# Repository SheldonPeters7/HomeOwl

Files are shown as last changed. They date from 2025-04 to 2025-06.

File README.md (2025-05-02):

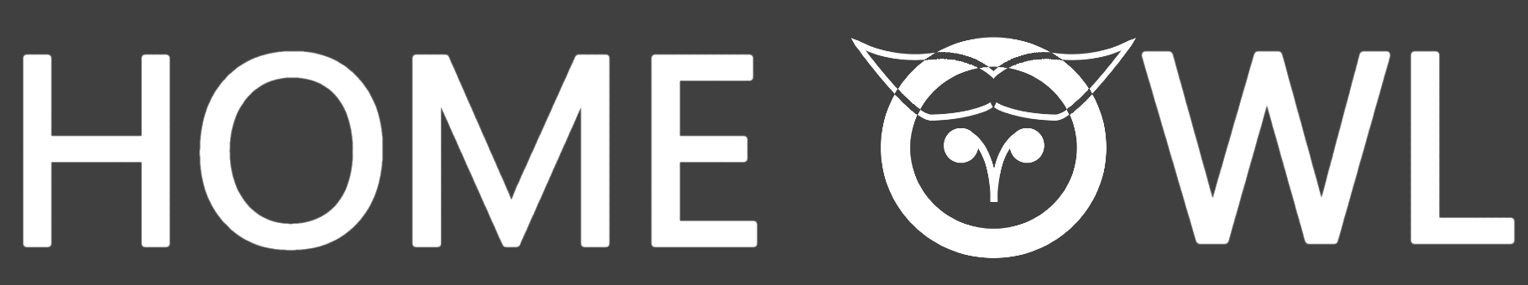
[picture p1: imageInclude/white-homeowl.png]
Home Owl

# Autonomous Security Robot

**CSU Channel Islands Capstone Project** <br>

<ins>Students:</ins> <br>
- Samantha Buckle <br>
- Dylan Dauz <br>
- Sameeh Olipani <br>
- Sheldon Peters <br>

<ins>Faculty Advisor:</ins> <br>
- Dr. Vida Vakilian

<ins>Background Information:</ins> <br>
Homes and commercial spaces face a variety of security risks like unauthorized entry or even unexpected disturbances. To address these potential issues, the Home Owl project developed a low cost, responsive platform for real time indoor surveillance in environments such as warehouses, offices, and homes. The Home Owl robot combines autonomous navigation with disturbance detection using PIR and sound sensors and offers remote control activation as well. It autonomously traverses a room, pauses briefly to allow sensor stabilization for reliable motion and audio monitoring, and sets off an alarm upon detecting anomalies. The robot’s structure was designed with 3D printed components and laser cut acrylic, resulting in a modular architecture that supports easy future upgrades.

<ins>Capstone Accomplishments Timeline</ins> <br>
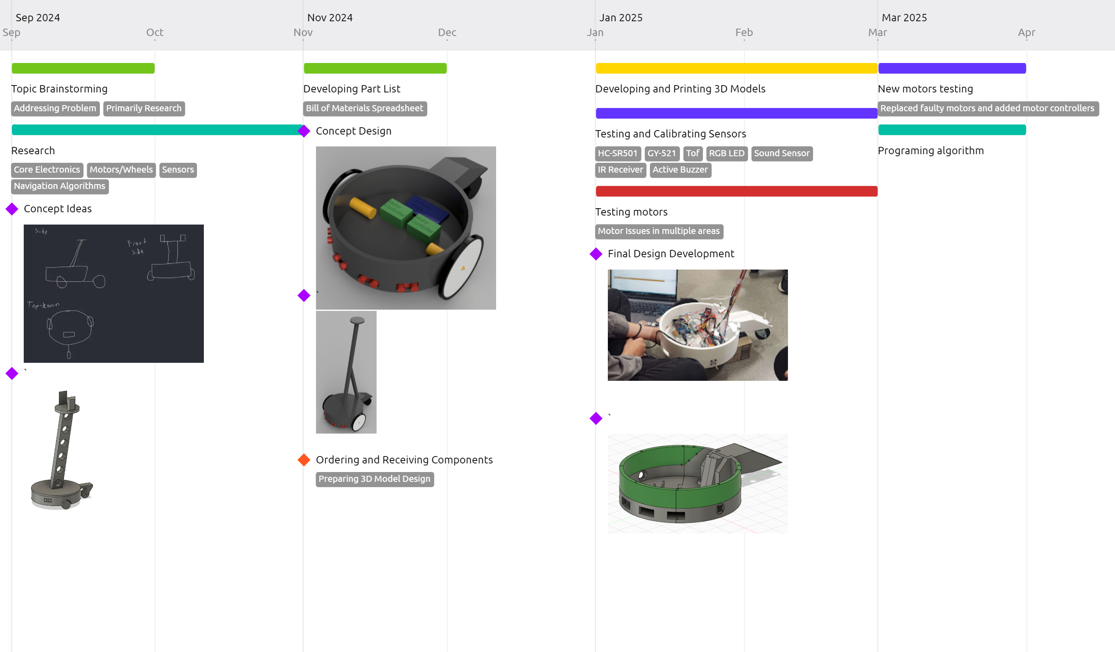
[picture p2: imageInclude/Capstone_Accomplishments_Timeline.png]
Timeline


<ins>3-D Print Model</ins> <br>
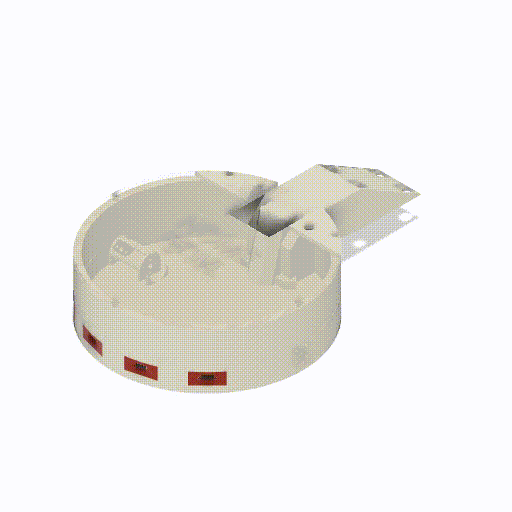
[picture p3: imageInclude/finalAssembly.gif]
Model


<ins>Video Demonstration:</ins> <br>
Home Owl (https://youtu.be/DmunYwZIAPI)

<ins>Poster Image:</ins> <br>
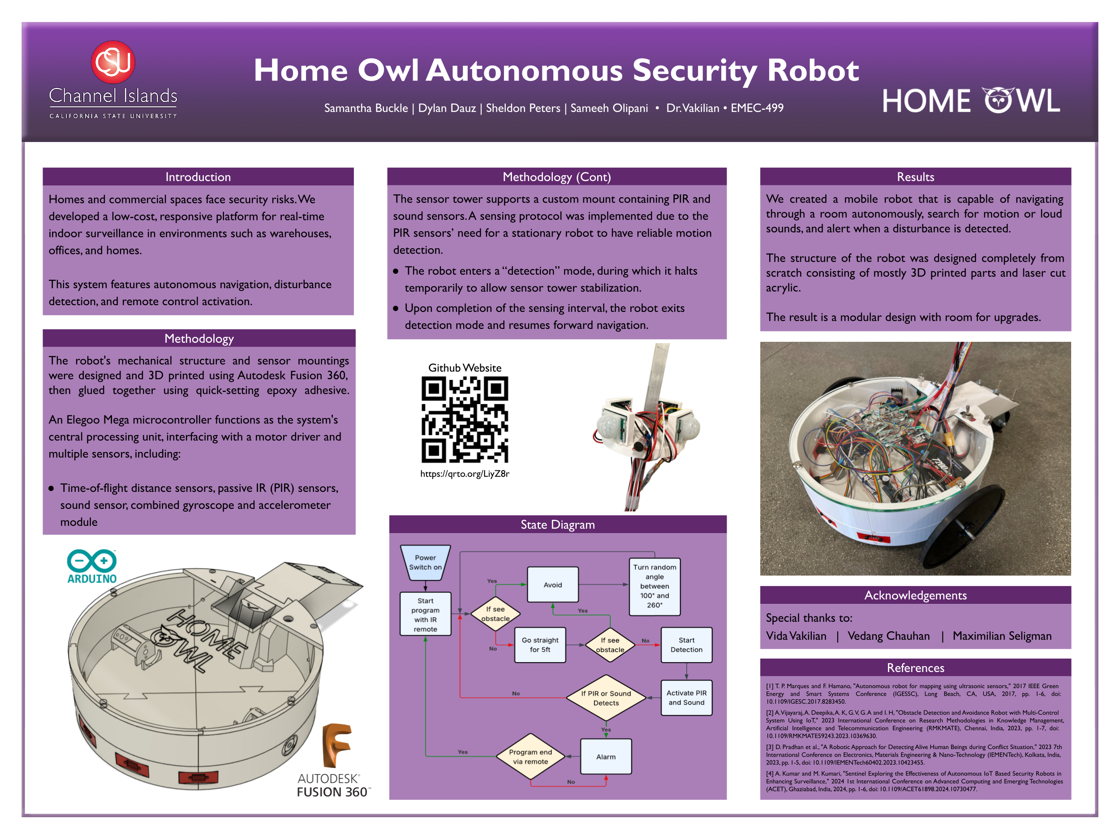
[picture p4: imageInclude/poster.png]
Poster


<ins>Wiring Diagram:</ins> <br>
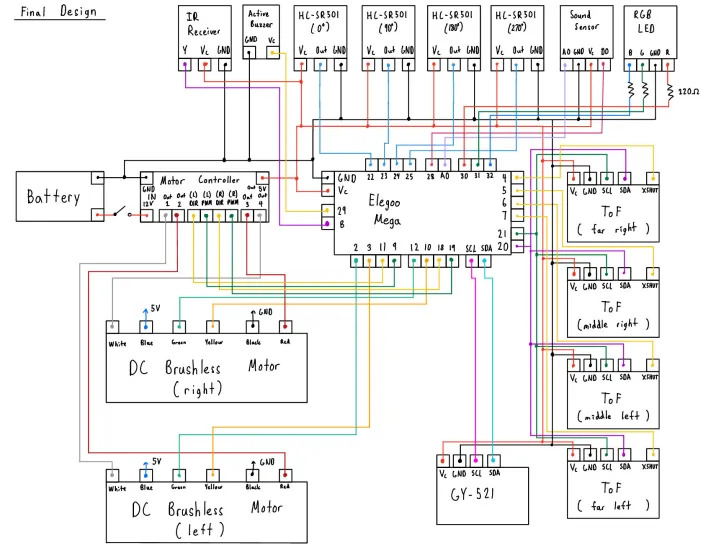
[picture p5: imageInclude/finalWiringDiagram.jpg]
Wiring


<ins>Acknowledgements:</ins> <br>
-  Dr. Vida Vakilian <br>
-  Dr. Vedang Chauhan <br>
- Maximilian Seligman <br>

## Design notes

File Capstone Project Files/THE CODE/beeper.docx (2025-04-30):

TEST CODE

int buzzerPin = 29; // Buzzer connected to digital pin 29

bool beepActive = false; // Control flag for beep mode

unsigned long previousMillis = 0;

const long beepInterval = 500; // 500ms beep toggle interval

// State variables for 3-second cycle

enum State { OFF, ON };

State currentState = OFF;

unsigned long stateStartTime = 0;

const long stateInterval = 3000; // 3 seconds per state

void setup() {

pinMode(buzzerPin, OUTPUT);

digitalWrite(buzzerPin, LOW); // Ensure buzzer starts off

stateStartTime = millis(); // Initialize state timing

}

void loop() {

unsigned long currentMillis = millis();

// Handle state transitions every 3 seconds

if (currentMillis - stateStartTime >= stateInterval) {

// Toggle state

currentState = (currentState == OFF) ? ON : OFF;

stateStartTime = currentMillis;

if (currentState == ON) {

beepActive = true; // Enable beeping

previousMillis = currentMillis; // Reset beep timer

} else {

beepActive = false; // Disable beeping

digitalWrite(buzzerPin, LOW); // Ensure buzzer is off

}

}

// Handle beep toggling when active

if (beepActive) {

if (currentMillis - previousMillis >= beepInterval) {

previousMillis = currentMillis;

digitalWrite(buzzerPin, !digitalRead(buzzerPin));

}

}

}

HEADER FILE FOR POTENTIAL IMPLEMENTATION

#ifndef Buzzer_h

#define Buzzer_h

#include <Arduino.h>

class Buzzer {

public:

Buzzer(int pin) : buzzerPin(pin), beepActive(false), previousMillis(0) {}

void init() {

pinMode(buzzerPin, OUTPUT);

digitalWrite(buzzerPin, LOW);

}

void update() {

if (beepActive) {

unsigned long currentMillis = millis();

if (currentMillis - previousMillis >= interval) {

previousMillis = currentMillis;

digitalWrite(buzzerPin, !digitalRead(buzzerPin));

}

}

}

void startBeep() {

beepActive = true;

previousMillis = millis();

digitalWrite(buzzerPin, HIGH); // Start with immediate beep

}

void stopBeep() {

beepActive = false;

digitalWrite(buzzerPin, LOW);

}

void setInterval(unsigned long newInterval) {

interval = newInterval;

}

private:

int buzzerPin;

bool beepActive;

unsigned long previousMillis;

unsigned long interval = 500; // Default 500ms interval

};

#endif

#include "Buzzer.h"

// Create buzzer instance on pin 29

Buzzer myBuzzer(29);

void setup() {

myBuzzer.init();

}

void loop() {

myBuzzer.update(); // Must call this regularly

// Example trigger - replace with your actual triggers

if (someCondition) {

myBuzzer.startBeep();

}

if (anotherCondition) {

myBuzzer.stopBeep();

}

// Rest of your code...

}

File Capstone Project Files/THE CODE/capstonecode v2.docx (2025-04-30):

const int leftencoderApin = 2;

const int leftencoderBpin = 3;

const int rightencoderApin = 18;

const int rightencoderBpin = 19;

const int leftdirpin = 11;

const int rightdirpin = 12;

const int leftpwmpin = 9;

const int rightpwmpin = 10;

int leftencoderpulse = 0; // ticks left

int rightencoderpulse = 0; // ticks right

// distance variables

double ipr = 18.85; // inches per revolution

double tpr = 950; // ticks per revolution

// PID variables

int pwm = 100; // pwm motor power

double error = 0; // set speed - actual speed

double eI = 0; // integral error

double eD = 0; // derivative error

double prev_error = 0;

const float Kp = 1.0; // proportional gain

const float Ki = 2.0; //integral gain

const float Kd = 1.0; // derivative gain

float targetAngle = 90;

int i = 0; // for motor start delay

// Odometry variables

const float wheelbase = 13.7; // inches

const float dpt = ipr / tpr;

float dL = 0; // distance left wheel traveled

float dR = 0; // distance right wheel traveled

float theta = 0;

void setup()

{

Serial.begin(9600);

pinMode(leftencoderApin, INPUT); //input_pullup to print to serial monitor..?

pinMode(leftencoderBpin, INPUT);

// Left encoder interrupts

attachInterrupt(digitalPinToInterrupt(leftencoderApin), ALeadingLeft, RISING);

attachInterrupt(digitalPinToInterrupt(leftencoderBpin), BLeadingLeft, RISING);

// Right encoder interrupts

attachInterrupt(digitalPinToInterrupt(rightencoderApin), ALeadingRight, RISING);

attachInterrupt(digitalPinToInterrupt(rightencoderBpin), BLeadingRight, RISING);

// target ticks

//targetticks = (targetdistance / ipr) * tpr;

pinMode(leftdirpin, OUTPUT);

pinMode(rightdirpin, OUTPUT);

pinMode(leftpwmpin, OUTPUT);

pinMode(rightpwmpin, OUTPUT);

analogWrite(leftpwmpin, 0);

analogWrite(rightpwmpin, 0);

delay(2000); // Allows the serial monitor to connect before robot starts

}

void loop()

{

// clockwise forward motion (hopefully)

digitalWrite(leftdirpin, HIGH);

digitalWrite(rightdirpin, LOW);

//unsigned long clock = millis();

//computePID();

//analogWrite(leftpwmpin, 255-pwm-45);

// Serial.println("before");

// Serial.println(i);

// // start delay on motors

// if(i < 1)

// {

// Serial.println("during");

// delay(2000);

// Serial.print(i);

// i++;

// }

// Serial.println("after");

// Serial.println(i);

//analogWrite(rightpwmpin, pwm);

changeAngle();

Serial.print("dl: ");

Serial.println(dL);

Serial.print("dr: ");

Serial.println(dR);

Serial.print("theta: ");

Serial.println(theta);

Serial.print("error: ");

Serial.println(error);

//Serial.print("left encoder pulse: ");

// Serial.println(leftencoderpulse);

// Serial.print(",");

// //Serial.print("right encoder pulse: ");

// Serial.println(rightencoderpulse);

delay(50);

// Serial.print("Distance Traveled: ");

// Serial.print((((leftencoderpulse + rightencoderpulse) / 2) / tpr) * ipr);

// Serial.println(" inches");

while(((leftencoderpulse + rightencoderpulse) / 2) >= tpr)

{

stopMotors();

//Serial.println("ENCODER STOPPED");

}

}

void stopMotors()

{

digitalWrite(leftdirpin, HIGH);

digitalWrite(rightdirpin, LOW);

analogWrite(leftpwmpin, 255);

analogWrite(rightpwmpin, 0);

}

void ALeadingLeft()

{

if(digitalRead(leftencoderBpin) == LOW)

{

leftencoderpulse--;

}

else

{

leftencoderpulse++;

}

}

void BLeadingLeft()

{

if(digitalRead(leftencoderApin) == LOW)

{

leftencoderpulse++;

}

else

{

leftencoderpulse--;

}

}

void ALeadingRight()

{

if(digitalRead(rightencoderBpin) == LOW)

{

rightencoderpulse++;

}

else

{

rightencoderpulse--;

}

}

void BLeadingRight()

{

if(digitalRead(rightencoderApin) == LOW)

{

rightencoderpulse--;

}

else

{

rightencoderpulse++;

}

}

void computePID()

{

error = targetAngle - theta;

eI = eI + error; // integral error

eD = prev_error - error; // derivative error

prev_error = error;

// limit overflow of intergral error

if (eI > 200)

{

eI = 0;

}

pwm = Kp * error + Ki * eI + Kd * eD; // P + I + D

if (pwm >= 360) // limit max

{

}

else if (pwm <= -360) // limit min

{

}

}

void computeAngle()

{

dL = leftencoderpulse * dpt;

dR = rightencoderpulse * dpt;

theta = (dL-dR)/wheelbase * (180/3.1415);

}

void changeAngle()

{

computeAngle();

error = targetAngle - theta;

if (error > 5) // turn left

{

digitalWrite(leftdirpin, LOW);

digitalWrite(rightdirpin, LOW);

analogWrite(leftpwmpin, 100+45);

analogWrite(rightpwmpin, 100);

} else if (error < -5) // this is the one we want to happen, turn right

{

digitalWrite(leftdirpin, HIGH);

digitalWrite(rightdirpin, HIGH);

analogWrite(leftpwmpin, 255-100-45);

analogWrite(rightpwmpin, 255-100);

}

else // default

{

stopMotors();

// digitalWrite(leftdirpin, HIGH);

// digitalWrite(rightdirpin, LOW);

// analogWrite(leftpwmpin, 255-100-45);

// analogWrite(rightpwmpin, 100);

delay(3000);

}

}

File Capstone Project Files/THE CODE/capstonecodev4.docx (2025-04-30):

#include <Wire.h>

const int leftencoderApin = 2;

const int leftencoderBpin = 3;

const int rightencoderApin = 18;

const int rightencoderBpin = 19;

const int leftdirpin = 11;

const int rightdirpin = 12;

const int leftpwmpin = 9;

const int rightpwmpin = 10;

int leftencoderpulse = 0;

int rightencoderpulse = 0;

// distance variables

double ipr = 18.85; // inches per revolution

double tpr = 900; // ticks per revolution

int targetangle = 0;

double targetdistance = 67;

int pwm = 100; // pwm motor power

// PID variables

double error = 0; // set speed - actual speed

double eI = 0; // integral error

double eD = 0; // derivative error

double prev_error = 0;

const float Kp = 1.2; // proportional gain

const float Ki = 0.3; //integral gain

const float Kd = 0; // derivative gain

float omega = 0;

float vL = 0;

float vR = 0;

int i = 0; // for motor start delay

const float wheelbase = 13.7; // inches

// Gyro Variables

const int MPU_ADDR = 0x68;

const float GYRO_SCALE = 131.0; // ±250°/s range

float yaw = 0;

float gyroZOffset = 0;

unsigned long prevTime = 0;

void setup()

{

Wire.begin();

Serial.begin(9600);

pinMode(leftencoderApin, INPUT); //input_pullup to print to serial monitor..?

pinMode(leftencoderBpin, INPUT);

// Left encoder interrupts

attachInterrupt(digitalPinToInterrupt(leftencoderApin), ALeadingLeft, RISING);

attachInterrupt(digitalPinToInterrupt(leftencoderBpin), BLeadingLeft, RISING);

// Right encoder interrupts

attachInterrupt(digitalPinToInterrupt(rightencoderApin), ALeadingRight, RISING);

attachInterrupt(digitalPinToInterrupt(rightencoderBpin), BLeadingRight, RISING);

pinMode(leftdirpin, OUTPUT);

pinMode(rightdirpin, OUTPUT);

pinMode(leftpwmpin, OUTPUT);

pinMode(rightpwmpin, OUTPUT);

analogWrite(leftpwmpin, 0);

analogWrite(rightpwmpin, 0);

// Gyro setup

Wire.beginTransmission(MPU_ADDR);

Wire.write(0x6B); // PWR_MGMT_1

Wire.write(0); // Wake up

Wire.endTransmission();

calibrateGyro();

prevTime = micros();

delay(2000); // Allows the serial monitor to connect before robot starts

}

void loop()

{

// clockwise forward motion

// digitalWrite(leftdirpin, HIGH);

// digitalWrite(rightdirpin, LOW);

//unsigned long clock = millis();

//computePID();

//analogWrite(leftpwmpin, 255-pwm-45);

// // start delay on motors

// if(i < 1)

// {

// delay(2000);

// i++;

// }

//analogWrite(rightpwmpin, pwm);

if(i < 1)

{

targetangle = yaw + 90;

i++;

}

computePID();

rotateRobotRight();

//Serial.print("left encoder pulse: ");

// Serial.println(leftencoderpulse);

// //Serial.print("right encoder pulse: ");

// Serial.println(rightencoderpulse);

// Read gyro Z-axis

int16_t rawGyroZ = readGyroZ();

float gyroZ = (rawGyroZ - gyroZOffset) / GYRO_SCALE;

// Calculate delta time

unsigned long currentTime = micros();

float dt = (currentTime - prevTime) / 1000000.0;

prevTime = currentTime;

// Integrate angular velocity to get yaw

yaw -= gyroZ * dt;

Serial.print("Yaw: ");

Serial.println(yaw, 2);

}

void stopMotors()

{

digitalWrite(leftdirpin, HIGH);

digitalWrite(rightdirpin, LOW);

analogWrite(leftpwmpin, 255);

analogWrite(rightpwmpin, 0);

}

void ALeadingLeft()

{

if(digitalRead(leftencoderBpin) == LOW)

{

leftencoderpulse--;

}

else

{

leftencoderpulse++;

}

}

void BLeadingLeft()

{

if(digitalRead(leftencoderApin) == LOW)

{

leftencoderpulse++;

}

else

{

leftencoderpulse--;

}

}

void ALeadingRight()

{

if(digitalRead(rightencoderBpin) == LOW)

{

rightencoderpulse++;

}

else

{

rightencoderpulse--;

}

}

void BLeadingRight()

{

if(digitalRead(rightencoderApin) == LOW)

{

rightencoderpulse--;

}

else

{

rightencoderpulse++;

}

}

void computePID()

{

error = targetangle - yaw;

eI = eI + error; // integral error

eD = prev_error - error; // derivative error

prev_error = error;

// limit overflow of intergral error

if (eI > 200)

{

eI = 0;

}

omega = Kp * error + Ki * eI + Kd * eD; // calculating rate of change of angle (rad/s)

if (omega >= 100) // limit max

{

omega = 100;

}

else if (omega <= 0) // limit min

{

omega = 0;

}

}

void rotateRobotRight()

{

vL = ((omega * wheelbase) / 2);

vR = ((omega * wheelbase) / 2);

if(targetangle > yaw)

{

digitalWrite(leftdirpin, HIGH);

digitalWrite(rightdirpin, HIGH);

analogWrite(leftpwmpin, 255-(vL*0.152) - 45);

analogWrite(rightpwmpin, 255-(vR*0.152));

} else

{

stopMotors();

}

}

int16_t readGyroZ()

{

Wire.beginTransmission(MPU_ADDR);

Wire.write(0x47); // GYRO_ZOUT_H

Wire.endTransmission(false);

Wire.requestFrom(MPU_ADDR, 2, true);

return Wire.read() << 8 | Wire.read();

}

void calibrateGyro()

{

Serial.println("Calibrating gyro... Keep sensor stationary!");

delay(1000);

long total = 0;

for(int i = 0; i < 1000; i++) {

total += readGyroZ();

delay(1);

}

gyroZOffset = total / 1000.0;

Serial.print("Calibration offset: ");

Serial.println(gyroZOffset);

}

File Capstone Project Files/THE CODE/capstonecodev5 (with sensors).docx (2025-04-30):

TRY (due to timer conflicts with pins)

// Motor Control (swap PWM pins)

const int leftpwmpin = 11; // Originally 9 (Timer1)

const int rightpwmpin = 12; // Originally 10 (Timer1)

const int leftdirpin = 9; // Swap direction pins

const int rightdirpin = 10;

---_------------------

// Arduino Mega

#elif defined(__AVR_ATmega1280__) || defined(__AVR_ATmega2560__)

//#define IR_USE_TIMER1

//#define IR_USE_TIMER2

//#define IR_USE_TIMER3

#define IR_USE_TIMER5 // Use Timer5 for IR decoding

// Add this after the Mega section

#elif defined(IR_USE_TIMER5)

#define TIMER_RESET_INTR_PENDING

#define TIMER_CONFIG_KHZ(val) ((val) / (timer5_prescale * 0.001))

#define TIMER_ENABLE_INTR (TIMSK5 = _BV(OCIE5A))

#define TIMER_DISABLE_INTR (TIMSK5 = 0)

#define TIMER_INTR_NAME TIMER5_COMPA_vect

#define TIMER_COUNT_TOP (F_CPU / timer5_prescale / 1000)

#if defined(TCCR5A) && defined(TCCR5B)

#define TIMER_CONFIG_GPIO() (DDRL |= _BV(PL0))

#define TIMER_PWM_PIN PL0 // Arduino Mega pin 44

#endif

#endif // End of timer selection block

—----

________________________________________________________--

#include <IRremote.h>

// IR Configuration

const int receiver = 8; // IR receiver pin

IRrecv irrecv(receiver); // Create IR receiver object

static uint32_t last_decodedRawData = 0; // Stores last received code

// State management

enum SystemState {

OFF,

STANDBY,

MOVING,

SEARCHING

};

SystemState currentState = OFF;

void setup() {

// IR initialization

irrecv.enableIRIn(); // Start the IR receiver

}

void loop() {

// Check for IR input

if (irrecv.decode()) {

translateIR();

irrecv.resume();

}

}

void translateIR() {

if (irrecv.decode()) {

static unsigned long lastIRTime = 0;

unsigned long currentTime = millis();

// Debounce - ignore repeats within 200ms

if (currentTime - lastIRTime > 200) {

lastIRTime = currentTime;

switch(irrecv.decodedIRData.decodedRawData) {

case 0xBA45FF00: // POWER button

if (currentState == OFF) {

currentState = STANDBY;

} else if (currentState == STANDBY) {

currentState = MOVING;

} else {

currentState = OFF;

}

break;

case 0xB847FF00: // RESET button

currentState = STANDBY;

break;

}

}

}

}

#include <Wire.h>

#include <Adafruit_VL53L0X.h>

const int leftencoderApin = 2;

const int leftencoderBpin = 3;

const int rightencoderApin = 18;

const int rightencoderBpin = 19;

const int leftdirpin = 11;

const int rightdirpin = 12;

const int leftpwmpin = 9;

const int rightpwmpin = 10;

int leftencoderpulse = 0;

int rightencoderpulse = 0;

int currentleftencoderpulse = 0;

int currentrightencoderpulse = 0;

// distance variables

double ipr = 18.85; // inches per revolution

double tpr = 900; // ticks per revolution

int targetangle = 0;

int pwm = 100; // pwm motor power

// PID variables

double error = 0; // set speed - actual speed

double eI = 0; // integral error

double eD = 0; // derivative error

double prev_error = 0;

const float Kp = 1.2; // proportional gain

const float Ki = 0.3; //integral gain

const float Kd = 0; // derivative gain

float omega = 0;

float vL = 0;

float vR = 0;

int i = 0; // for motor start delay

const float wheelbase = 13.7; // inches

bool runonceturn = false; // the run once bool for turning

// Gyro Variables

const int MPU_ADDR = 0x68;

const float GYRO_SCALE = 131.0; // ±250°/s range

float yaw = 0;

float gyroZOffset = 0;

unsigned long prevTime = 0;

// const unsigned long yawPrintInterval = 1000; // Print every 1000 ms

// unsigned long lastYawPrint = 0; // Timing tracker

// ToF Variables

Adafruit_VL53L0X loxFarRight = Adafruit_VL53L0X(); // Pin 4

Adafruit_VL53L0X loxMidRight = Adafruit_VL53L0X(); // Pin 5

Adafruit_VL53L0X loxMidLeft = Adafruit_VL53L0X(); // Pin 6

Adafruit_VL53L0X loxFarLeft = Adafruit_VL53L0X(); // Pin 7

#define XSHUT_FAR_RIGHT 4

#define XSHUT_MID_RIGHT 5

#define XSHUT_MID_LEFT 6

#define XSHUT_FAR_LEFT 7

unsigned long lastToFRead = 0;

float distanceFarRight = 0;

float distanceMidRight = 0;

float distanceMidLeft = 0;

float distanceFarLeft = 0;

float distancethreshold = 200;

bool farRight = (distanceFarRight <= distancethreshold);

bool midRight = (distanceMidRight <= distancethreshold);

bool midLeft = (distanceMidLeft <= distancethreshold);

bool farLeft = (distanceFarLeft <= distancethreshold);

/***************************** Sound & Motion Sensors *****************************/

// Sound and Motion Variables

const int sensorAnalogPin = A0; // Analog input

const int sensorDigitalPin = 28; // Digital input D28

const int ledPin = LED_BUILTIN; // Built-in LED

// Sound detection settings

unsigned long lastNoiseTime = 0;

const unsigned long noiseCooldown = 1000;

int loudNoiseThreshold;

int quietLevel;

// PIR Sensor Pins (Inputs)

int pirPin1 = 22; // HC-SR501 #1

int pirPin2 = 23; // HC-SR501 #2

int pirPin3 = 24; // HC-SR501 #3

int pirPin4 = 25; // HC-SR501 #4

// Motion detection settings

unsigned long lastMotionTime = 0;

const unsigned long motionCooldown = 1000;

/***************************** Start of Setup *****************************/

void setup()

{

Serial.begin(115200);

Wire.begin();

pinMode(leftencoderApin, INPUT); //input_pullup to print to serial monitor..?

pinMode(leftencoderBpin, INPUT);

// Left encoder interrupts

attachInterrupt(digitalPinToInterrupt(leftencoderApin), ALeadingLeft, RISING);

attachInterrupt(digitalPinToInterrupt(leftencoderBpin), BLeadingLeft, RISING);

// Right encoder interrupts

attachInterrupt(digitalPinToInterrupt(rightencoderApin), ALeadingRight, RISING);

attachInterrupt(digitalPinToInterrupt(rightencoderBpin), BLeadingRight, RISING);

pinMode(leftdirpin, OUTPUT);

pinMode(rightdirpin, OUTPUT);

pinMode(leftpwmpin, OUTPUT);

pinMode(rightpwmpin, OUTPUT);

// digitalWrite(leftdirpin, HIGH);

// digitalWrite(rightdirpin, LOW);

analogWrite(leftpwmpin, 0);

analogWrite(rightpwmpin, 0);

// Gyro setup (Initialize MPU)

Wire.beginTransmission(MPU_ADDR);

Wire.write(0x6B); // PWR_MGMT_1

Wire.write(0); // Wake up

Wire.endTransmission();

calibrateGyro();

prevTime = micros();

// Initialize ToF sensors

pinMode(XSHUT_FAR_RIGHT, OUTPUT);

pinMode(XSHUT_MID_RIGHT, OUTPUT);

pinMode(XSHUT_MID_LEFT, OUTPUT);

pinMode(XSHUT_FAR_LEFT, OUTPUT);

initializeSensor(loxFarRight, XSHUT_FAR_RIGHT, 0x30, "Far Right");

initializeSensor(loxMidRight, XSHUT_MID_RIGHT, 0x31, "Middle Right");

initializeSensor(loxMidLeft, XSHUT_MID_LEFT, 0x32, "Middle Left");

initializeSensor(loxFarLeft, XSHUT_FAR_LEFT, 0x33, "Far Left");

// Initialize sound/motion sensors

pinMode(sensorDigitalPin, INPUT);

pinMode(ledPin, OUTPUT);

pinMode(pirPin1, INPUT);

pinMode(pirPin2, INPUT);

pinMode(pirPin3, INPUT);

pinMode(pirPin4, INPUT);

calibrateSensor();

Serial.println("System initialization complete!");

delay(2000); // Allows the serial monitor to connect before robot starts

}

void loop()

{

// clockwise forward motion

//digitalWrite(leftdirpin, HIGH);

//digitalWrite(rightdirpin, LOW);

//unsigned long clock = millis();

//computePID();

//analogWrite(leftpwmpin, 255-pwm-45);

// start delay on motors

// if(i < 1)

// {

// delay(2000);

// i++;

// }

//analogWrite(rightpwmpin, pwm);

readAllToFSensors();

//delay(3000);

if(checkFrontObstacle())

{

double randomTurn = random(100, 260);

Serial.println("Object Detected");

readAllToFSensors();

runonceturn = true;

stopMotors();

targetangle = yaw + randomTurn;

// Serial.println(farRight);

// Serial.println(farLeft);

// Serial.println(midRight);

// Serial.println(midLeft);

delay(1000);

while(runonceturn == true)

{

updateGyro();

Serial.println(yaw);

Serial.println(targetangle);

Serial.println("TURNING");

computePID();

turnRight();

//Serial.println("I Turned");

//runonceturn = false;

Serial.println(runonceturn);

}

Serial.println("I finished turning");

} else if ((leftencoderpulse < (currentleftencoderpulse + 60*(tpr/ipr))) && (rightencoderpulse < (currentrightencoderpulse + 60*(tpr/ipr))))// left encoder pulse and right in coder pulse less than current left encoder pulse plus 5ft and current right encoder pulse pluse 5ft

{

Serial.println("normal case ");

digitalWrite(leftdirpin, HIGH);

digitalWrite(rightdirpin, LOW);

analogWrite(leftpwmpin, 255-pwm-45);

analogWrite(rightpwmpin, pwm);

updateGyro();

} else

{

stopMotors();

delay(3000);

//intruderSense()

currentleftencoderpulse = leftencoderpulse;

currentrightencoderpulse = rightencoderpulse;

}

// Handle ToF sensor readings

if (millis() - lastToFRead >= 1000) {

readAllToFSensors();

lastToFRead = millis();

}

// Monitor environment

//checkSound();

//checkMotion();

}

void stopMotors()

{

digitalWrite(leftdirpin, HIGH);

digitalWrite(rightdirpin, LOW);

analogWrite(leftpwmpin, 255);

analogWrite(rightpwmpin, 0);

}

void ALeadingLeft()

{

if(digitalRead(leftencoderBpin) == LOW)

{

leftencoderpulse--;

}

else

{

leftencoderpulse++;

}

}

void BLeadingLeft()

{

if(digitalRead(leftencoderApin) == LOW)

{

leftencoderpulse++;

}

else

{

leftencoderpulse--;

}

}

void ALeadingRight()

{

if(digitalRead(rightencoderBpin) == LOW)

{

rightencoderpulse++;

}

else

{

rightencoderpulse--;

}

}

void BLeadingRight()

{

if(digitalRead(rightencoderApin) == LOW)

{

rightencoderpulse--;

}

else

{

rightencoderpulse++;

}

}

void computePID()

{

error = targetangle - yaw;

eI = eI + error; // integral error

eD = prev_error - error; // derivative error

prev_error = error;

// limit overflow of intergral error

if (eI > 200)

{

eI = 0;

}

omega = Kp * error + Ki * eI + Kd * eD; // calculating rate of change of angle (rad/s)

if (omega >= 150) // limit max

{

omega = 150;

}

else if (omega <= 0) // limit min

{

omega = 0;

}

}

void turnRight()

{

vL = ((omega * wheelbase) / 2);

vR = ((omega * wheelbase) / 2);

if(targetangle > yaw)

{

digitalWrite(leftdirpin, HIGH);

digitalWrite(rightdirpin, HIGH);

analogWrite(leftpwmpin, 255-(vL*0.152) - 45);

analogWrite(rightpwmpin, 255-(vR*0.152));

} else

{

stopMotors();

runonceturn = false;

}

}

int16_t readGyroZ()

{

Wire.beginTransmission(MPU_ADDR);

Wire.write(0x47); // GYRO_ZOUT_H

Wire.endTransmission(false);

Wire.requestFrom(MPU_ADDR, 2, true);

return Wire.read() << 8 | Wire.read();

}

void calibrateGyro()

{

Serial.println("Calibrating gyro... Keep sensor stationary!");

delay(1000);

long total = 0;

for(int i = 0; i < 1000; i++)

{

total += readGyroZ();

delay(1);

}

gyroZOffset = total / 1000.0;

Serial.print("Calibration offset: ");

Serial.println(gyroZOffset);

}

void updateGyro()

{

int16_t rawGyroZ = readGyroZ();

float gyroZ = (rawGyroZ - gyroZOffset) / GYRO_SCALE;

unsigned long currentTime = micros();

float dt = (currentTime - prevTime) / 1000000.0;

prevTime = currentTime;

yaw -= gyroZ * dt;

}

/********************************* ToF Functions *********************************/

void initializeSensor(Adafruit_VL53L0X &sensor, int xshutPin, uint8_t newAddress, const char* position)

{

digitalWrite(xshutPin, LOW);

delay(10);

digitalWrite(xshutPin, HIGH);

delay(10);

if (!sensor.begin(newAddress))

{

Serial.print(position);

Serial.println(" sensor failed to boot!");

while(1);

}

Serial.print(position);

Serial.print(" sensor initialized at 0x");

Serial.println(newAddress, HEX);

}

int readSensor(Adafruit_VL53L0X &sensor, const char* position)

{

VL53L0X_RangingMeasurementData_t measure;

sensor.rangingTest(&measure, false);

if(measure.RangeStatus != 4)

{

Serial.print(position);

Serial.print(": ");

Serial.print(measure.RangeMilliMeter);

Serial.println(" mm");

return(measure.RangeMilliMeter);

} else

{

Serial.print(position);

Serial.println(": Out of range");

return(-1);

}

}

void readAllToFSensors()

{

distanceFarRight = readSensor(loxFarRight, "Far Right");

distanceMidRight = readSensor(loxMidRight, "Middle Right");

distanceMidLeft = readSensor(loxMidLeft, "Middle Left");

distanceFarLeft = readSensor(loxFarLeft, "Far Left");

}

bool checkFrontObstacle()

{

VL53L0X_RangingMeasurementData_t measure;

bool obstacleDetected = false;

// Check first sensor

loxFarLeft.rangingTest(&measure, false);

obstacleDetected |= (measure.RangeMilliMeter <= 400 && measure.RangeStatus != 4);

// Check second sensor

loxMidLeft.rangingTest(&measure, false);

obstacleDetected |= (measure.RangeMilliMeter <= 400 && measure.RangeStatus != 4);

// Check third sensor

loxMidRight.rangingTest(&measure, false);

obstacleDetected |= (measure.RangeMilliMeter <= 400 && measure.RangeStatus != 4);

// Check fourth sensor

loxFarRight.rangingTest(&measure, false);

obstacleDetected |= (measure.RangeMilliMeter <= 400 && measure.RangeStatus != 4);

return obstacleDetected;

}

/****************************** Sound/Motion Functions ****************************/

void calibrateSensor()

{

long sum = 0;

for(int i = 0; i < 50; i++) sum += analogRead(sensorAnalogPin);

quietLevel = sum / 50;

loudNoiseThreshold = 400; // Hard-coded for testing

Serial.println("Sound sensor calibrated");

}

void checkSound()

{

int analogValue = analogRead(sensorAnalogPin);

int digitalValue = digitalRead(sensorDigitalPin);

if((analogValue > loudNoiseThreshold) && (digitalValue == HIGH) &&

(millis() - lastNoiseTime > noiseCooldown)) {

handleNoiseDetection(analogValue);

triggerActionSound();

}

}

void handleNoiseDetection(int noiseLevel)

{

lastNoiseTime = millis();

Serial.print("LOUD NOISE! Level: ");

Serial.println(noiseLevel);

for(int i = 0; i < 3; i++)

{

digitalWrite(ledPin, HIGH);

delay(100);

digitalWrite(ledPin, LOW);

delay(100);

}

}

void triggerActionSound()

{

Serial.println("Action: Sound detected!");

}

void checkMotion()

{

if((digitalRead(pirPin1) || digitalRead(pirPin2) ||

digitalRead(pirPin3) || digitalRead(pirPin4)) &&

(millis() - lastMotionTime > motionCooldown))

{

handleMotionDetection();

}

}

void handleMotionDetection()

{

lastMotionTime = millis();

Serial.println("Motion detected");

}

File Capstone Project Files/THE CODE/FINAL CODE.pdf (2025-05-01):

#include <Wire.h>

#include <Adafruit_VL53L0X.h> #include <IRremote.h>

const int leftencoderApin = 2; const int leftencoderBpin = 3; const int rightencoderApin = 18; const int rightencoderBpin = 19; const int leftdirpin = 9;
const int rightdirpin = 10; const int leftpwmpin = 11; const int rightpwmpin = 12;

int leftencoderpulse = 0;
int rightencoderpulse = 0;
int currentleftencoderpulse = 0; int currentrightencoderpulse = 0;
// distance variables
double ipr = 18.85; // inches per revolution double tpr = 900; // ticks per revolution int targetangle = 0;
int pwm = 100; // pwm motor power
int offset = 5; // motor power offset
// PID variables
double error = 0; // set speed - actual speed double eI = 0; // integral error
double eD = 0; // derivative error
double prev_error = 0;
const float Kp = 1.8; // proportional gain const float Ki = 0.4; //integral gain const float Kd = 0.05; // derivative gain float omega = 0;
float vL = 0;
float vR = 0;
int i = 0; // for motor start delay
const float wheelbase = 13.7; // inches
bool runonceturn = false; // the run once bool for turning // Gyro Variables
const int MPU_ADDR = 0x68;

const float GYRO_SCALE = 131.0; // ±250°/s range float yaw = 0;
float gyroZOffset = 0;
unsigned long prevTime = 0;
// IR Configuration
const int receiver = 8; | // IR receiver pin
IRrecv irrecv(receiver); | // Create IR receiver object
static uint32_t last_decodedRawData = 0; // Stores last received code // State management
enum SystemState {
OFF,
STANDBY,
MOVING,
SEARCHING
};
SystemState currentState = OFF;
// ToF Variables
Adafruit_VL53L0X loxFarRight = Adafruit_VL53L0X(); // Pin 4 Adafruit_VL53L0X loxMidRight = Adafruit_VL53L0X(); // Pin 5
Adafruit_VL53L0X loxMidLeft = Adafruit_VL53L0X(); | // Pin 6
Adafruit_VL53L0X loxFarLeft = Adafruit_VL53L0X(); | // Pin 7

#define XSHUT_FAR_RIGHT 4

#define XSHUT_MID_RIGHT 5

#define XSHUT_MID_LEFT 6

#define XSHUT_FAR_LEFT 7

unsigned long lastToFRead = 0;

float distanceFarRight = 0; float distanceMidRight = 0; float distanceMidLeft = 0; float distanceFarLeft = 0;
float distancethreshold = 200;
bool farRight = (distanceFarRight <= distancethreshold); bool midRight = (distanceMidRight <= distancethreshold); bool midLeft = (distanceMidLeft <= distancethreshold); bool farLeft = (distanceFarLeft <= distancethreshold);

// Sound and Motion Variables

const int sensorAnalogPin = A0; | // Analog input
const int sensorDigitalPin = 28; | // Digital input D28
const int ledPin = LED_BUILTIN; | // Built-in LED
const int buzzerPin = 29; | // Buzzer output
unsigned long lastDisturbanceTime = 0;
const unsigned long debounceTime = 500; // 0.5s debounce

// LED Configuration
#define RED 30

#define GREEN 31

#define BLUE 32

// Search mode variables
bool disturbanceDetected = false;
int flashState = 0;
const long beepInterval = 500; // 500ms beep/flash interval

// Sound detection settings
unsigned long lastNoiseTime = 0;
const unsigned long noiseCooldown = 1000; int loudNoiseThreshold;
int quietLevel;

unsigned long startMillis;
unsigned long currentMillis;
unsigned long detectionDuration = 10000; // 10 seconds in milliseconds

// PIR Sensor Pins (Inputs)
int pirPin1 = 22; // HC-SR501 #1 int pirPin2 = 23; // HC-SR501 #2 int pirPin3 = 24; // HC-SR501 #3 int pirPin4 = 25; // HC-SR501 #4

// Motion detection settings
unsigned long lastMotionTime = 0;
const unsigned long motionCooldown = 1000;

/***************************** Start of Setup *****************************/

void setup()
{

Serial.begin(115200);
Wire.begin();
pinMode(leftencoderApin, INPUT); pinMode(leftencoderBpin, INPUT);
// Left encoder interrupts attachInterrupt(digitalPinToInterrupt(leftencoderApin), ALeadingLeft, RISING); attachInterrupt(digitalPinToInterrupt(leftencoderBpin), BLeadingLeft, RISING); // Right encoder interrupts attachInterrupt(digitalPinToInterrupt(rightencoderApin), ALeadingRight, RISING);
attachInterrupt(digitalPinToInterrupt(rightencoderBpin), BLeadingRight, RISING);
pinMode(leftdirpin, OUTPUT);
pinMode(rightdirpin, OUTPUT); pinMode(leftpwmpin, OUTPUT); pinMode(rightpwmpin, OUTPUT); analogWrite(leftpwmpin, 0); analogWrite(rightpwmpin, 0);

pinMode(RED, OUTPUT);
pinMode(GREEN, OUTPUT);
pinMode(BLUE, OUTPUT);
digitalWrite(RED, HIGH);
digitalWrite(GREEN, LOW);
digitalWrite(BLUE, LOW);
// Gyro setup (Initialize MPU) Wire.beginTransmission(MPU_ADDR); Wire.write(0x6B); // PWR_MGMT_1 Wire.write(0); // Wake up
Wire.endTransmission();
calibrateGyro();
prevTime = micros();
// Initialize ToF sensors
pinMode(XSHUT_FAR_RIGHT, OUTPUT); pinMode(XSHUT_MID_RIGHT, OUTPUT); pinMode(XSHUT_MID_LEFT, OUTPUT);

pinMode(XSHUT_FAR_LEFT, OUTPUT);

initializeSensor(loxFarRight, XSHUT_FAR_RIGHT, 0x30, "Far Right"); initializeSensor(loxMidRight, XSHUT_MID_RIGHT, 0x31, "Middle Right"); initializeSensor(loxMidLeft, XSHUT_MID_LEFT, 0x32, "Middle Left"); initializeSensor(loxFarLeft, XSHUT_FAR_LEFT, 0x33, "Far Left");
// Initialize sound/motion sensors
pinMode(sensorDigitalPin, INPUT);
pinMode(ledPin, OUTPUT);
pinMode(pirPin1, INPUT);
pinMode(pirPin2, INPUT);
pinMode(pirPin3, INPUT);
pinMode(pirPin4, INPUT);
pinMode(buzzerPin, OUTPUT);
// IR initialization
irrecv.enableIRIn(); // Start the IR receiver calibrateSensor();
Serial.println("System initialization complete!");
delay(200); // Allows the serial monitor to connect before robot starts }

void loop()
{
// Check for IR input
if (irrecv.decode())
{
translateIR();
irrecv.resume();
}
readAllToFSensors(); // constantly checks values of ToF sensors to see if something is within range
if(currentState == OFF) {
stopMotors();
digitalWrite(RED, HIGH);
digitalWrite(GREEN, LOW);
digitalWrite(BLUE, LOW);
digitalWrite(buzzerPin, LOW); }

if(currentState == MOVING) { digitalWrite(buzzerPin, LOW); if(checkFrontObstacle()) // OBSTACLE CASE {
digitalWrite(buzzerPin, LOW);
double randomTurn = random(100, 260); // generate random angle to turn to Serial.println("Object Detected");
readAllToFSensors();
runonceturn = true; // prepare to turn stopMotors();
targetangle = yaw + randomTurn;

delay(1000);
// starts turning and updating gyro/pid as it turns while(runonceturn == true)
{
updateGyro();
computePID();
turnRight();
}
} else if ((leftencoderpulse < (currentleftencoderpulse + 84*(tpr/ipr))) && (rightencoderpulse < (currentrightencoderpulse + 84*(tpr/ipr))))// left encoder pulse and right in coder pulse less than current left encoder pulse plus 5ft and current right encoder pulse pluse 5ft
{
// NORMAL CASE | Green (G = HIGH)
digitalWrite(RED, LOW);
digitalWrite(GREEN, HIGH); digitalWrite(BLUE, LOW);
digitalWrite(buzzerPin, LOW); digitalWrite(leftdirpin, HIGH); digitalWrite(rightdirpin, LOW); analogWrite(leftpwmpin, 255-pwm-offset); // OFFSET LINE analogWrite(rightpwmpin, pwm);
updateGyro();
} else
{
// SENSING CASE
stopMotors();

// Blue (B=HIGH) Stablizing digitalWrite(RED, LOW);
digitalWrite(GREEN, LOW);
digitalWrite(BLUE, HIGH);
delay(2500); // allows for sensor tower to stop wobbling
// sense
startMillis = millis(); // Record the start time when entering the else loop

while (millis() - startMillis < detectionDuration) {
// Searching
digitalWrite(RED, LOW);
digitalWrite(GREEN, HIGH); digitalWrite(BLUE, HIGH);
if (checkDisturbances())
{
disturbanceDetected = true; flashSearchLights();
}
// Optional: Add a small delay to prevent overwhelming the loop delay(100);
}
currentleftencoderpulse = leftencoderpulse; currentrightencoderpulse = rightencoderpulse; }
}
// Handle ToF sensor readings
if (millis() - lastToFRead >= 1000) {
readAllToFSensors();
lastToFRead = millis();
}
}

void stopMotors()
{
digitalWrite(leftdirpin, HIGH); digitalWrite(rightdirpin, LOW);

analogWrite(leftpwmpin, 255); analogWrite(rightpwmpin, 0); }

void ALeadingLeft()
{
if(digitalRead(leftencoderBpin) == LOW) {
leftencoderpulse--;
}
else
{
leftencoderpulse++;
}
}

void BLeadingLeft()
{
if(digitalRead(leftencoderApin) == LOW) {
leftencoderpulse++;
}
else
{
leftencoderpulse--;
}
}

void ALeadingRight()
{
if(digitalRead(rightencoderBpin) == LOW) {
rightencoderpulse++;
}
else
{
rightencoderpulse--;
}
}

void BLeadingRight()
{
if(digitalRead(rightencoderApin) == LOW) {
rightencoderpulse--;
}
else
{
rightencoderpulse++;
}
}
void computePID()
{
error = targetangle - yaw;
eI = eI + error; // integral error
eD = prev_error - error; // derivative error prev_error = error;

// limit overflow of intergral error if (eI > 200)
{
eI = 0;
}
omega = Kp * error + Ki * eI + Kd * eD; // calculating rate of change of angle (rad/s)

if (omega >= 100) // limit max {
omega = 100;
}
else if (omega <= 0) // limit min {
omega = 0;
}
}
void turnRight()
{
vL = ((omega * wheelbase) / 2); vR = ((omega * wheelbase) / 2);

if(targetangle > yaw)
{
digitalWrite(leftdirpin, HIGH);
digitalWrite(rightdirpin, HIGH);
analogWrite(leftpwmpin, 255-(vL*0.152)-45); // OFFSET LINE analogWrite(rightpwmpin, 255-(vR*0.152));
} else
{
stopMotors();
runonceturn = false;
}
}

int16_t readGyroZ()
{
Wire.beginTransmission(MPU_ADDR); Wire.write(0x47); // GYRO_ZOUT_H Wire.endTransmission(false); Wire.requestFrom(MPU_ADDR, 2, true);
return Wire.read() << 8 | Wire.read();
}

void calibrateGyro()
{
Serial.println("Calibrating gyro... Keep sensor stationary!"); delay(1000);

long total = 0;
for(int i = 0; i < 1000; i++) {
total += readGyroZ();
delay(1);
}
gyroZOffset = total / 1000.0; Serial.print("Calibration offset: "); Serial.println(gyroZOffset);
}

void updateGyro()

{
int16_t rawGyroZ = readGyroZ();
float gyroZ = (rawGyroZ - gyroZOffset) / GYRO_SCALE;

unsigned long currentTime = micros();
float dt = (currentTime - prevTime) / 1000000.0; prevTime = currentTime;

yaw -= gyroZ * dt;
}

/********************************* ToF Functions *********************************/
void initializeSensor(Adafruit_VL53L0X &sensor, int xshutPin, uint8_t newAddress, const char* position)
{
digitalWrite(xshutPin, LOW); delay(10);
digitalWrite(xshutPin, HIGH); delay(10);
if (!sensor.begin(newAddress)) {
Serial.print(position);
Serial.println(" sensor failed to boot!"); while(1);
}
Serial.print(position);
Serial.print(" sensor initialized at 0x"); Serial.println(newAddress, HEX);
}

int readSensor(Adafruit_VL53L0X &sensor, const char* position) {
VL53L0X_RangingMeasurementData_t measure; sensor.rangingTest(&measure, false);

if(measure.RangeStatus != 4)
{

Serial.print(position);
Serial.print(": ");
Serial.print(measure.RangeMilliMeter); Serial.println(" mm");
return(measure.RangeMilliMeter);
} else
{
Serial.print(position);
Serial.println(": Out of range"); return(-1);
}

}

void readAllToFSensors()
{
distanceFarRight = readSensor(loxFarRight, "Far Right"); distanceMidRight = readSensor(loxMidRight, "Middle Right"); distanceMidLeft = readSensor(loxMidLeft, "Middle Left"); distanceFarLeft = readSensor(loxFarLeft, "Far Left");
}

bool checkFrontObstacle()
{
VL53L0X_RangingMeasurementData_t measure; bool obstacleDetected = false;

// Check first sensor
loxFarLeft.rangingTest(&measure, false);
obstacleDetected |= (measure.RangeMilliMeter <= 500 && measure.RangeStatus != 4);

// Check second sensor
loxMidLeft.rangingTest(&measure, false);
obstacleDetected |= (measure.RangeMilliMeter <= 500 && measure.RangeStatus != 4);

// Check third sensor
loxMidRight.rangingTest(&measure, false);

obstacleDetected |= (measure.RangeMilliMeter <= 500 && measure.RangeStatus != 4);

// Check fourth sensor
loxFarRight.rangingTest(&measure, false);
obstacleDetected |= (measure.RangeMilliMeter <= 500 && measure.RangeStatus != 4);

return obstacleDetected;
}

/****************************** Sound/Motion Functions ****************************/

bool checkDisturbances()
{
// Read PIR sensors (true = motion detected)
bool motionDetected = digitalRead(pirPin1) || digitalRead(pirPin2) || digitalRead(pirPin3) || digitalRead(pirPin4);

// Read analog sound level (higher values = louder)
bool soundDetected = analogRead(sensorAnalogPin) > loudNoiseThreshold;

// Check with debounce timer
if ((motionDetected || soundDetected) && (millis() - lastDisturbanceTime > debounceTime))
{
lastDisturbanceTime = millis(); disturbanceDetected = true; return true;
}
return false;
}

void handleIntruderDetection()
{
Serial.println("Intruder detected!"); digitalWrite(buzzerPin, HIGH);

disturbanceDetected = true; }

void flashSearchLights()
{
static unsigned long lastFlashTime = 0;

if (millis() - lastFlashTime >= beepInterval) {
lastFlashTime = millis();
flashState = !flashState;

if (flashState)
{
// Red Buzzer ON
digitalWrite(RED, HIGH);
digitalWrite(GREEN, LOW);
digitalWrite(BLUE, LOW);
digitalWrite(buzzerPin, HIGH); } else
{
// Buzzer Cyan
digitalWrite(RED, LOW);
digitalWrite(GREEN, HIGH); digitalWrite(BLUE, HIGH);
digitalWrite(buzzerPin, LOW); }
}
}

////// IR
void calibrateSensor()
{
// Auto-calibrate to ambient noise long sum = 0;
for(int i = 0; i < 50; i++)
{
sum += analogRead(sensorAnalogPin); delay(20);

}
loudNoiseThreshold = (sum / 50) + 400; // Set threshold 400 above average Serial.print("Calibrated sound threshold: "); Serial.println(loudNoiseThreshold);
}
void translateIR() {
if (irrecv.decode()) {
static unsigned long lastIRTime = 0; unsigned long currentTime = millis();

// Debounce - ignore repeats within 200ms if (currentTime - lastIRTime > 200) { lastIRTime = currentTime;

switch(irrecv.decodedIRData.decodedRawData) { case 0xBA45FF00: // POWER button
if (currentState == OFF) {
currentState = MOVING;
} else if (currentState == STANDBY) { currentState = MOVING;
} else {
currentState = OFF;
}
break;

case 0xB847FF00: // RESET button currentState = STANDBY;
break;
}
}
}
}

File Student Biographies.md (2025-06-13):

# Student Biographies

<ins>Samantha Buckle:</ins> <br>
Hi, I'm Samantha Buckle and I'm graduating with a B.S in Mechatronics Engineering, a Minor in Math, and a Minor in Computer Science. This has been a really fun project and learning opportunity with skills I hope to take into future jobs!

<ins>Dylan Dauz:</ins> <br>
My name is Dylan Dauz I am a graduating senior majoring in Mechatronics with a minor in Math. With this project, I am excited to showcase the culmination of my education here at CSUCI.

<ins>Sameeh Olipani:</ins> <br>
Hello there. I am Sameeh Olipani and I am graduating with a degree in Mechatronics. I have enjoyed this major and this project, and I feel that it will help me in my future internship and job at NAVSEA.

<ins>Sheldon Peters:</ins> <br>
Sheldon Peters is an undergraduate student at California State University Channel Islands (CSUCI), pursuing a degree in Mechatronics Engineering. With a passion for robotics and automation, Sheldon focuses on the integration of mechanical, electronic, and software systems in engineering applications. Currently, they are exploring innovative ways to enhance robotic design and adaptability. Sheldon plans to further their research in the field of engineering, with the goal of contributing to the development of cutting edge robotic technologies. Their future aspirations include advancing robotic engineering through research and creating impactful solutions for real world problems.

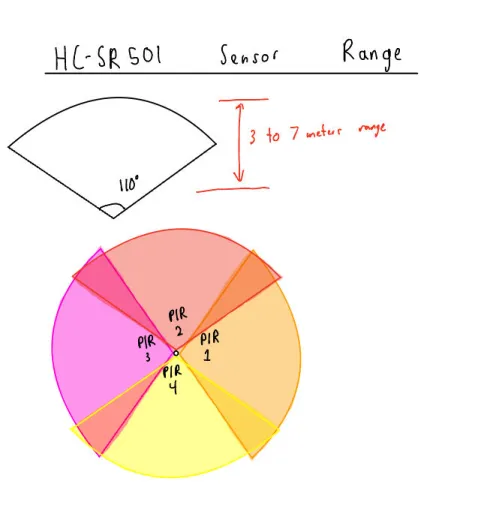
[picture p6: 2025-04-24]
Capstone Project Files/Images/HC-SR501 Sensor Range.webp

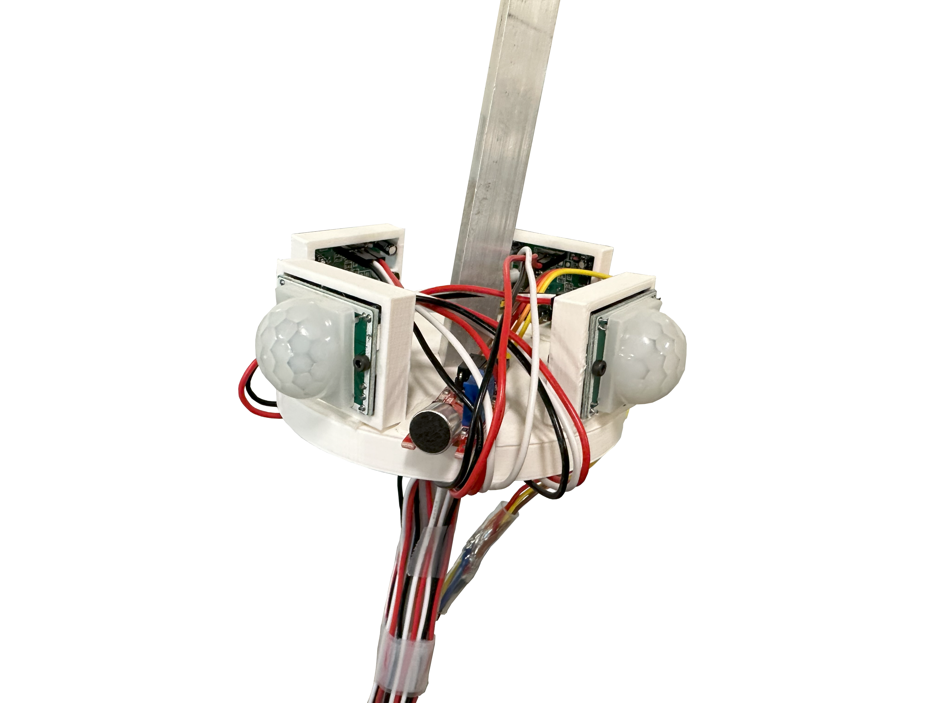
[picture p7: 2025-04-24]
Capstone Project Files/Images/Final Pictures/SensorTower.png

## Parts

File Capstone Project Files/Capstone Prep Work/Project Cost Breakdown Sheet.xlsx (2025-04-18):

Item Name | Link to item | Unit Amount | Cost per unit | Shipping Cost | Tax Cost | Total Cost | Cost (Split by 4) | Initial Purchaser | Purchase Date
ELEGOO Mega (with kit) | amazon (https://www.amazon.com/EL-KIT-008-Project-Complete-Ultimate-TUTORIAL/dp/B01EWNUUUA) | 1.00 | $52.79 | $0.00 | $3.83 | $56.62 | $14.15 | Sheldon | 2024-10-25
28mm Brushless DC Planetary Gear Motor, 12V, 68RPM | Roboshop (https://www.robotshop.com/products/e-s-motor-28mm-brushless-dc-planetary-gear-motor-12v-68rpm) | 2.00 | $30.50 | $23.50 | $5.64 | $90.14 | $22.54 | Sameeh | 2024-11-22
300W 5-50V PWM DC Brushless Electric Motor Speed Controller with Hall-Less Encoder | amazon (https://www.amazon.com/RioRand-Brushless-Electric-Controller-Hall-Less/dp/B087M3GVYX/) | 2.00 | $14.39 | $0.00 | $7.08 | $35.86 | $8.96 | Sameeh | 2024-11-22
5PCS HC-SR501 PIR Sensor | amazon (https://www.amazon.com/DIYmall-HC-SR501-Infrared-Sensor-Arduino/dp/B07CSM3K63?s=industrial) | 1.00 | $9.49 | $0.00 | $0.00 | $9.49 | $2.37 | sameeh | 2024-11-22
5PCS LM393 Sound Sensor | amazon (https://www.amazon.com/Stemedu-LM393-Sound-Sensor-Module/dp/B086ZHJCJB?s=industrial) | 1.00 | $9.98 | $0.00 | $0.00 | $9.98 | $2.50 | sameeh | 2024-11-22
5PCS VL53L0X Time-of-Flight (ToF) Laser Ranging Sensor | amazon (https://www.amazon.com/VL53L0X-Breakout-GY-VL53L0XV2-Distance-Measurement/dp/B0B1M99L67?hvadid=693270340479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) | 1.00 | $20.99 | $0.00 | $0.00 | $20.99 | $5.25 | sameeh | 2024-11-22
Caster wheel | amazon (https://www.amazon.com/Heavy-Rubber-Caster-Wheel-Swiveling/dp/B004672ZGA) | 1.00 | $7.39 | $0.00 | $0.00 | $7.39 | $1.85 | sameeh | 2024-11-22
Wheel | ServoCity (https://www.servocity.com/6-abs-disc-wheel/) | 2.00 | $5.99 | $5.67 | $2.59 | $20.24 | $5.06 | Dylan | 2024-11-25
Wheel Hub | ServoCity (https://www.servocity.com/1309-series-sonic-hub-6mm-d-bore/) | 2.00 | $7.99 | $0.00 | $0.00 | $15.98 | $4.00 | Dylan | 2024-11-25
Metal Rod 1, 6Pcs 40mm x 6mm |  | 1.00 | $9.99 |  |  |  |  | Sameeh | 2025-04-05
MECCANIXITY Shaft Coupling 4 t |  | 2.00 | $10.41 |  | $2.80 |  |  | Sameeh | 2025-04-05

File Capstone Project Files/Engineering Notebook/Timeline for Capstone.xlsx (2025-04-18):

Feb 24-28 | March 3-7 | March 10-14 | SPRING BREAK | March 24-28 | March 31 - April 4 | April 7-11 | April 14-18 | April 21-25 | April 28 - May 2
Assemble base | PROGRESS PRESENTATION |  |  | PIR Sensor Testing |  | PROGRESS PRESENTATION |  |  | CAPSTONE SHOWCASE
Assemble components onto base | Polishing base (from glue) | PIR sensors |  | Sound sensor functionality |  | Final Print Deadline | Deadline for poster?
Start navigation programming | Assemble components onto base | Motors encoders |  | Motor encoders
Test sensor interference | Testing locatiomotion
 | Start PID (turning)

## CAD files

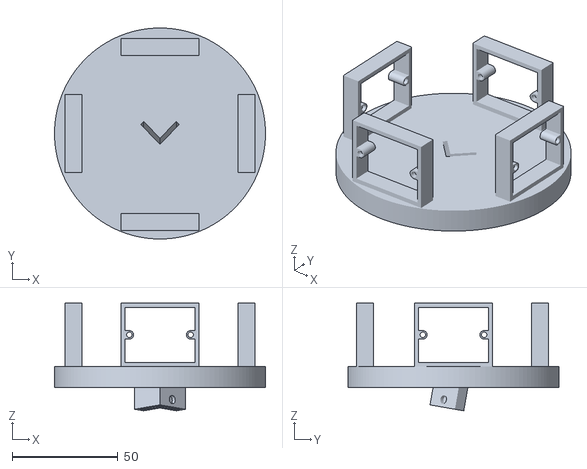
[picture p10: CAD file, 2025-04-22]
Capstone Project Files/Fusion 360 files/Capstone 3D Models/Capstone/Prototype/Tower Assembly.stl
100.0 x 100.0 x 51.0

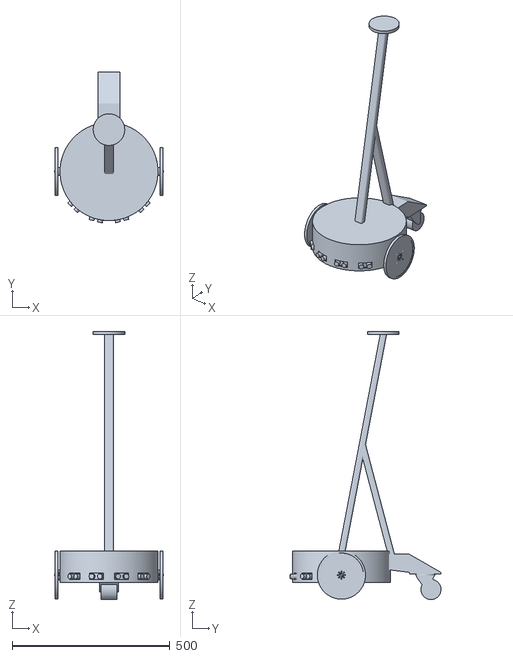
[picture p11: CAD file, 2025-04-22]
Capstone Project Files/Fusion 360 files/Capstone 3D Models/Capstone/Rough Draft 2/Draft Assembly.stl
346.0 x 477.8 x 848.2

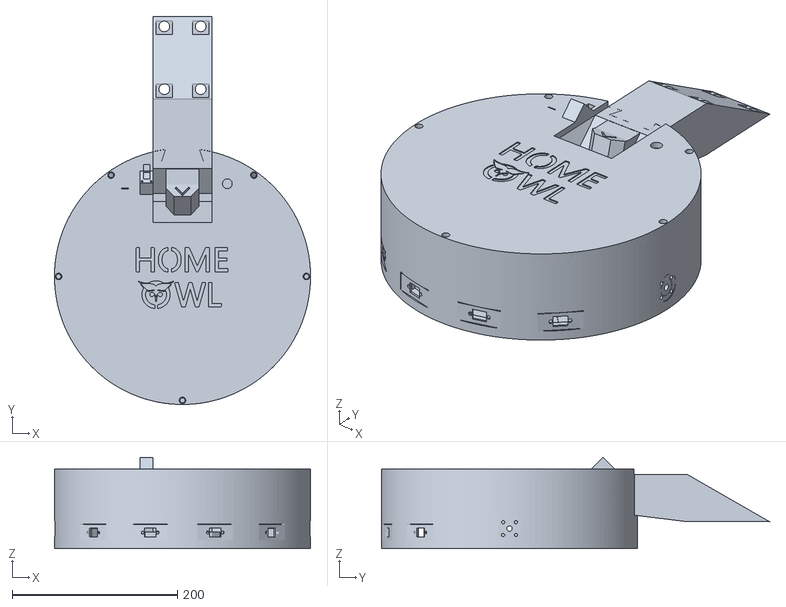
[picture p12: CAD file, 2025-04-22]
Capstone Project Files/Fusion 360 files/Capstone 3D Models/Capstone/Prototype/Final Assembly.stl
310.0 x 469.7 x 110.5

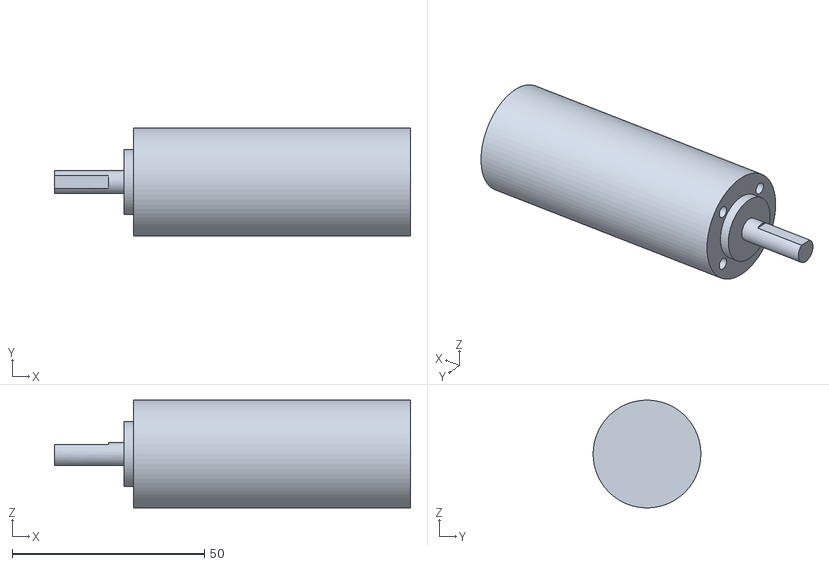
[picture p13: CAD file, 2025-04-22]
Capstone Project Files/Fusion 360 files/Capstone 3D Models/Capstone/Measured Parts/Motor.stl
92.5 x 28.0 x 28.0

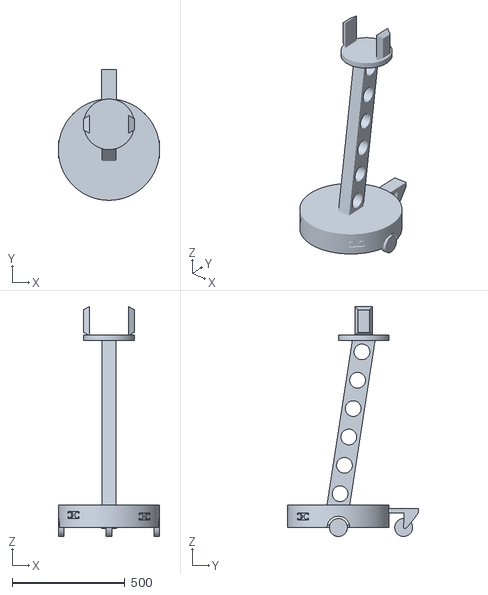
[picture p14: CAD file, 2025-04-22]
Capstone Project Files/Fusion 360 files/Capstone 3D Models/Capstone/Rough Draft 1/Rough Draft.stl
450.0 x 580.0 x 1021.3

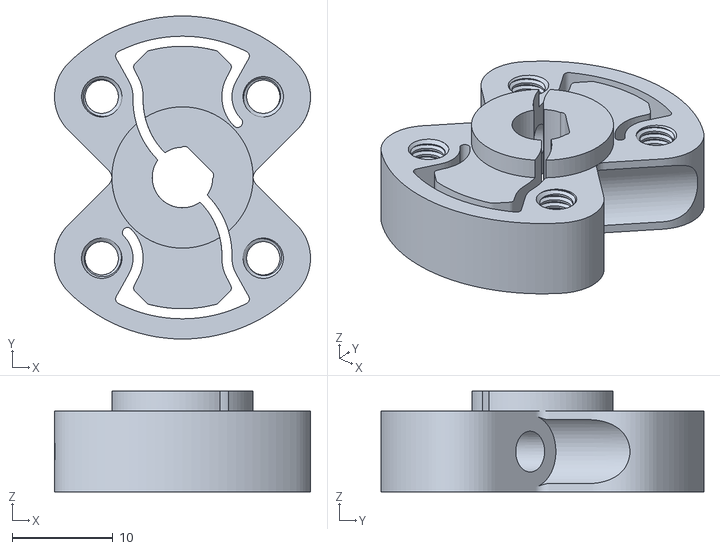
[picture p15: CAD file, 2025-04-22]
Capstone Project Files/Fusion 360 files/Capstone 3D Models/Capstone/Rough Draft 2/Wheel Hub.stl
25.4 x 32.0 x 10.0

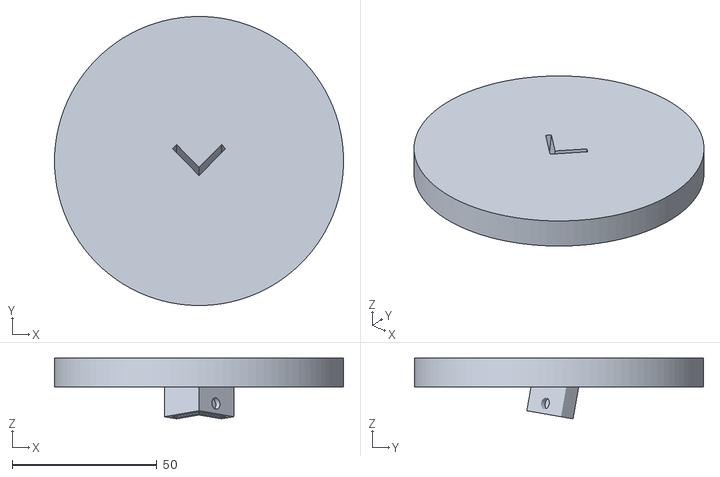
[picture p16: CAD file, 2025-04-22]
Capstone Project Files/Fusion 360 files/Capstone 3D Models/Capstone/Prototype/Temp Tower Top.stl
100.0 x 100.0 x 21.0

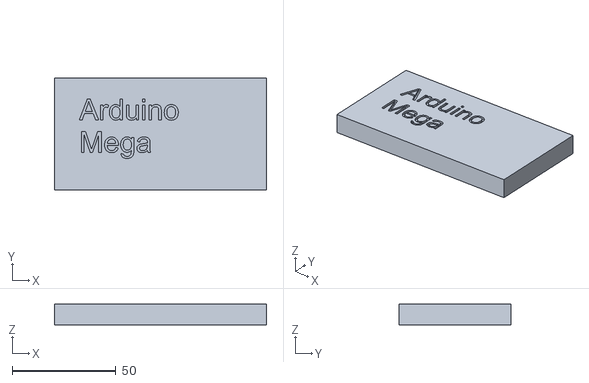
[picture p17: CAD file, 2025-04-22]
Capstone Project Files/Fusion 360 files/Capstone 3D Models/Capstone/Rough Draft 2/Arduino Mega Placeholder.stl
102.0 x 54.0 x 10.0

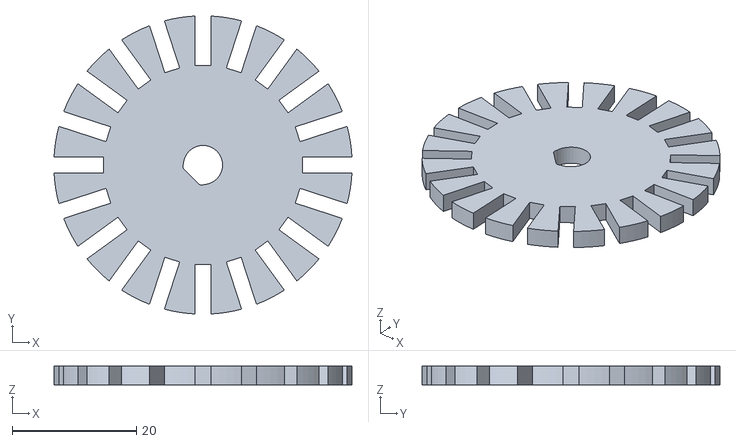
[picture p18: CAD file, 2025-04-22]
Capstone Project Files/Fusion 360 files/Capstone 3D Models/Capstone/Prototype/Encoder Disc.stl
47.9 x 47.9 x 3.00

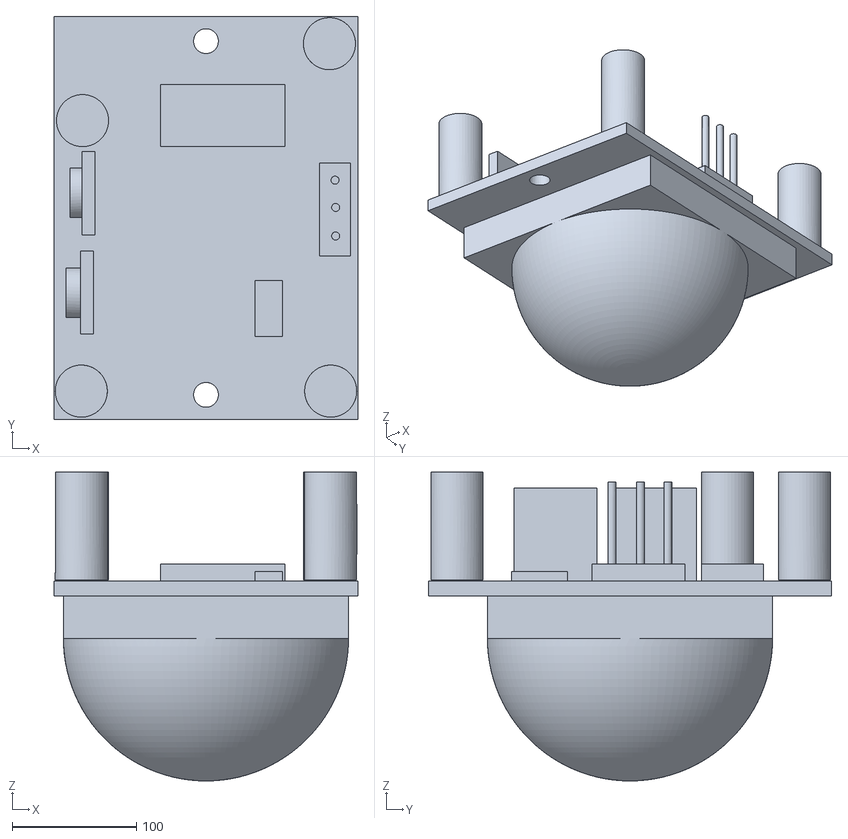
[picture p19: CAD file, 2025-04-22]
Capstone Project Files/Fusion 360 files/Capstone 3D Models/Capstone/Rough Draft 2/HC-SR501_PIR_MOTION.stl
245.0 x 325.0 x 249.0

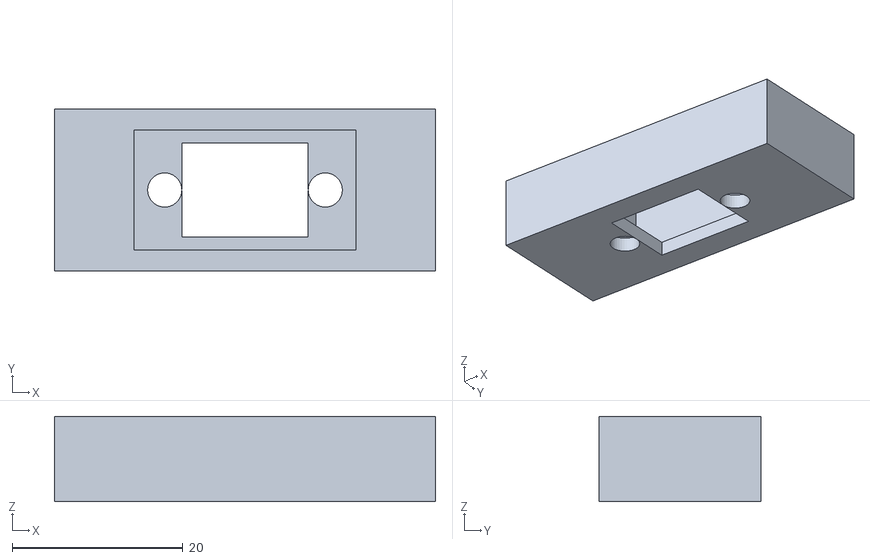
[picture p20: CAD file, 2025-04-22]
Capstone Project Files/Fusion 360 files/Capstone 3D Models/Capstone/Prototype/ToF Mount.stl
44.6 x 19.0 x 10.0

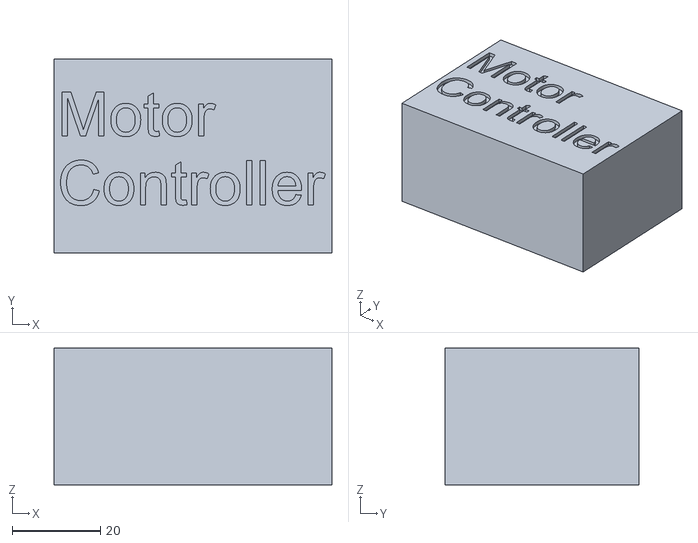
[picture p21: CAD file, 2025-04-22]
Capstone Project Files/Fusion 360 files/Capstone 3D Models/Capstone/Rough Draft 2/Motor Controller Placeholder.stl
63.0 x 44.0 x 31.0

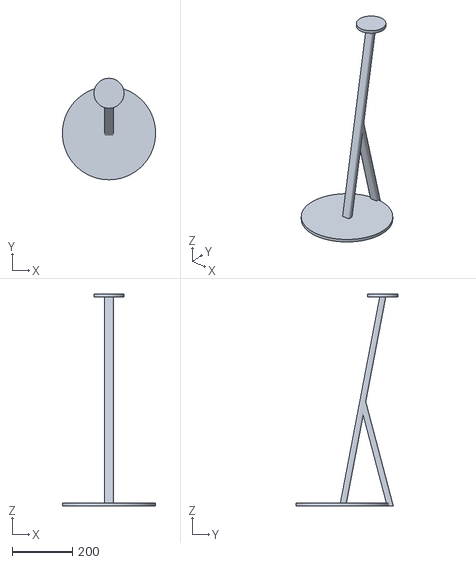
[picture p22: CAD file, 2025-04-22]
Capstone Project Files/Fusion 360 files/Capstone 3D Models/Capstone/Rough Draft 2/Lid and Sensor Tower.stl
310.0 x 337.8 x 704.9

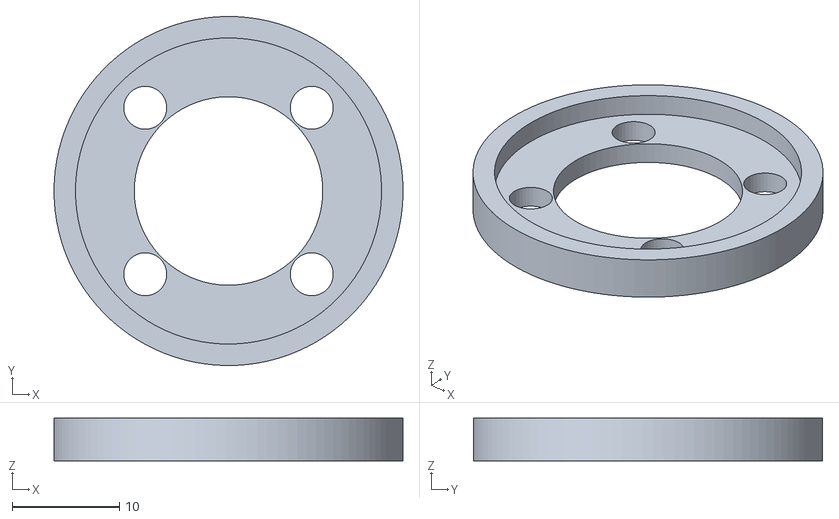
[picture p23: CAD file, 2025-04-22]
Capstone Project Files/Fusion 360 files/Capstone 3D Models/Capstone/Prototype/test 3.stl
32.5 x 32.5 x 4.00

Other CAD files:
Capstone Project Files/Fusion 360 files/Capstone 3D Models/Capstone/Rough Draft 2/Wheel.stl
Capstone Project Files/Fusion 360 files/Capstone 3D Models/Capstone/Rough Draft 2/Caster Wheel.stl
Capstone Project Files/Fusion 360 files/Capstone 3D Models/Capstone/Prototype/Arduino Mega Mount Plate.stl
Capstone Project Files/Fusion 360 files/Capstone 3D Models/Capstone/Prototype/1.5 thick 3m screw spacer.stl
Capstone Project Files/Fusion 360 files/Capstone 3D Models/Capstone/Prototype/Encoder Asembly.stl
Capstone Project Files/Fusion 360 files/Capstone 3D Models/Capstone/Prototype/Motor Controller Base Plate.stl
Capstone Project Files/Fusion 360 files/Capstone 3D Models/Capstone/Prototype/Motor Mount Converter.stl
Capstone Project Files/Fusion 360 files/Capstone 3D Models/Capstone/Prototype/PIR Mount.stl
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

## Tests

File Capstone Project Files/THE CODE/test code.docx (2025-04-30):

#include <Wire.h>

#include <Adafruit_VL53L0X.h>

#include <IRremote.h>

/******************************* Pin Definitions ********************************/

// Function prototypes

void calibrateGyro();

void updateGyro();

int16_t readGyroZ();

// ToF XSHUT Pins

#define XSHUT_FAR_RIGHT 4

#define XSHUT_MID_RIGHT 5

#define XSHUT_MID_LEFT 6

#define XSHUT_FAR_LEFT 7

// Motor Control

const int leftencoderApin = 2;

const int leftencoderBpin = 3;

const int rightencoderApin = 18;

const int rightencoderBpin = 19;

const int leftdirpin = 11;

const int rightdirpin = 12;

const int leftpwmpin = 9;

const int rightpwmpin = 10;

// IR & LEDs

#define RED 30

#define GREEN 31

#define BLUE 32

const int receiver = 8; // IR receiver pin

// Sound & Motion

const int sensorAnalogPin = A0;

const int sensorDigitalPin = 28;

const int ledPin = LED_BUILTIN;

const int pirPin1 = 22;

const int pirPin2 = 23;

const int pirPin3 = 24;

const int pirPin4 = 25;

const int buzzerPin = 29; // Buzzer connected to digital pin 29

/***************************** Sensor Objects ***********************************/

Adafruit_VL53L0X loxFarRight = Adafruit_VL53L0X();

Adafruit_VL53L0X loxMidRight = Adafruit_VL53L0X();

Adafruit_VL53L0X loxMidLeft = Adafruit_VL53L0X();

Adafruit_VL53L0X loxFarLeft = Adafruit_VL53L0X();

IRrecv irrecv(receiver);

/***************************** Global Variables *********************************/

enum SystemState {

OFF,

STANDBY,

MOVING,

SEARCHING

};

SystemState currentState = OFF;

float yaw = 0; // Current heading from gyro

float gyroZOffset = 0; // Gyro calibration offset

unsigned long prevTime = 0; // For gyro timing

double ipr = 18.85; // Inches per revolution (from your comment)

double tpr = 900; // Ticks per revolution (from your comment)

int loudNoiseThreshold = 400; // Sound detection threshold

const float TARGET_DISTANCE = 10.0 * 304.8; // 5ft in mm

const float wheelbase = 13.7; // inches

float vL = 0;

float vR = 0;

volatile int leftencoderpulse = 0;

volatile int rightencoderpulse = 0;

static uint32_t last_decodedRawData = 0;

const unsigned long GYRO_CALIBRATION_TIME = 2000;

const unsigned long SEARCH_STABILIZE_TIME = 2000;

const unsigned long SEARCH_DURATION = 10000;

bool initialCalibrationDone = false;

static unsigned long lastDisturbanceTime = 0;

const unsigned long debounceTime = 500; // 0.5s debounce

bool beepActive = false; // Control flag for beep mode

unsigned long previousBeepMillis = 0;

const long beepInterval = 500; // 500ms beep toggle interval

float error = 0, eI = 0, eD = 0, prev_error = 0;

const float Kp = 1.2, Ki = 0.3, Kd = 0;

float omega = 0;

int targetangle = 0;

void computePID() {

error = targetangle - yaw;

eI += error;

eD = error - prev_error;

prev_error = error;

// Anti-windup

eI = constrain(eI, -200, 200);

omega = Kp*error + Ki*eI + Kd*eD;

omega = constrain(omega, -100, 100);

}

float accumulatedDistance = 0;

bool obstacleDetected = false;

unsigned long searchPhaseStart = 0;

bool disturbanceDetected = false;

int flashState = 0;

/***************************** LED Control *************************************/

void setLedState(SystemState state) {

// No change if already in correct state

static SystemState lastState = OFF;

if (state == lastState) return;

lastState = state;

// Turn all off first

digitalWrite(RED, LOW);

digitalWrite(GREEN, LOW);

digitalWrite(BLUE, LOW);

switch(state) {

case OFF:

digitalWrite(RED, HIGH);

break;

case STANDBY:

digitalWrite(RED, HIGH);

digitalWrite(GREEN, HIGH);

break;

case MOVING:

digitalWrite(GREEN, HIGH);

break;

case SEARCHING:

digitalWrite(BLUE, HIGH);

break;

}

}

/***************************** Gyro Functions **********************************/

int16_t readGyroZ() {

Wire.beginTransmission(0x68);

Wire.write(0x47);

Wire.endTransmission(false);

Wire.requestFrom(0x68, 2, true);

return Wire.read() << 8 | Wire.read();

}

void updateGyro() {

int16_t rawGyroZ = readGyroZ();

float gyroZ = (rawGyroZ - gyroZOffset) / 131.0; // ±250dps range

unsigned long currentTime = micros();

float dt = (currentTime - prevTime) / 1000000.0;

prevTime = currentTime;

yaw += gyroZ * dt;

}

void calibrateGyro() {

Serial.println("Calibrating gyro...");

long total = 0;

for(int i = 0; i < 1000; i++) {

total += readGyroZ();

delay(1);

}

gyroZOffset = total / 1000.0;

Serial.print("Gyro offset: ");

Serial.println(gyroZOffset);

}

void setup() {

Serial.begin(115200);

Wire.begin();

// Initialize motor control pins

pinMode(leftdirpin, OUTPUT);

pinMode(rightdirpin, OUTPUT);

pinMode(leftpwmpin, OUTPUT);

pinMode(rightpwmpin, OUTPUT);

analogWrite(leftpwmpin, 0);

analogWrite(rightpwmpin, 0);

// Initialize encoder interrupts

pinMode(leftencoderApin, INPUT);

pinMode(leftencoderBpin, INPUT);

pinMode(rightencoderApin, INPUT);

pinMode(rightencoderBpin, INPUT);

attachInterrupt(digitalPinToInterrupt(leftencoderApin), ALeadingLeft, RISING);

attachInterrupt(digitalPinToInterrupt(leftencoderBpin), BLeadingLeft, RISING);

attachInterrupt(digitalPinToInterrupt(rightencoderApin), ALeadingRight, RISING);

attachInterrupt(digitalPinToInterrupt(rightencoderBpin), BLeadingRight, RISING);

// Initialize LEDs

pinMode(RED, OUTPUT);

pinMode(GREEN, OUTPUT);

pinMode(BLUE, OUTPUT);

// Initialize PIR sensors

pinMode(pirPin1, INPUT);

pinMode(pirPin2, INPUT);

pinMode(pirPin3, INPUT);

pinMode(pirPin4, INPUT);

// Initialize buzzer

pinMode(buzzerPin, OUTPUT);

digitalWrite(buzzerPin, LOW); // Ensure buzzer starts off

// Initialize ToF sensors

pinMode(XSHUT_FAR_RIGHT, OUTPUT);

pinMode(XSHUT_MID_RIGHT, OUTPUT);

pinMode(XSHUT_MID_LEFT, OUTPUT);

pinMode(XSHUT_FAR_LEFT, OUTPUT);

initializeSensor(loxFarRight, XSHUT_FAR_RIGHT, 0x30, "Far Right");

initializeSensor(loxMidRight, XSHUT_MID_RIGHT, 0x31, "Middle Right");

initializeSensor(loxMidLeft, XSHUT_MID_LEFT, 0x32, "Middle Left");

initializeSensor(loxFarLeft, XSHUT_FAR_LEFT, 0x33, "Far Left");

// Initialize IR receiver

irrecv.enableIRIn();

// Initialize MPU

Wire.beginTransmission(0x68);

Wire.write(0x6B); // PWR_MGMT_1

Wire.write(0); // Wake up

Wire.endTransmission();

// Calibrate sensors

calibrateGyro();

calibrateSensor();

// Initial state

currentState = OFF;

setLedState(OFF);

Serial.println("System initialization complete!");

delay(2000); // Initial stabilization

}

/***************************** Main Loop ***************************************/

void loop() {

// Update sensor data

updateGyro();

// Handle IR input

if (irrecv.decode()) {

translateIR();

irrecv.resume();

}

// State machine processing

processStateMachine();

// Optional: Add periodic debug prints if needed

static unsigned long lastPrint = 0;

if (millis() - lastPrint > 1000) {

Serial.print("State: ");

Serial.print(currentState);

Serial.print(" | Distance: ");

Serial.print(accumulatedDistance);

Serial.print(" | Yaw: ");

Serial.println(yaw);

lastPrint = millis();

}

}

/***************************** ToF Sensor Initialization ***********************/

void initializeSensor(Adafruit_VL53L0X &sensor, int xshutPin, uint8_t newAddress, const char* position) {

digitalWrite(xshutPin, LOW);

delay(10);

digitalWrite(xshutPin, HIGH);

delay(10);

if (!sensor.begin(newAddress)) {

Serial.print(position);

Serial.println(" sensor failed to boot!");

while(1);

}

Serial.print(position);

Serial.print(" sensor initialized at 0x");

Serial.println(newAddress, HEX);

}

/***************************** Modified Core Functions **********************************/

void processStateMachine() {

static SystemState previousState = OFF;

// Only process if state changed

if (currentState != previousState) {

previousState = currentState;

switch (currentState) {

case STANDBY:

handleStandby();

break;

case MOVING:

handleMoving();

break;

case SEARCHING:

handleSearching();

break;

case OFF:

handleOff();

break;

}

}

// Continuous processing for certain states

if (currentState == MOVING) {

// Obstacle detection and movement

if (checkFrontObstacle()) {

handleObstacle();

} else {

moveForward();

updateDistance();

if (accumulatedDistance >= TARGET_DISTANCE) {

transitionToSearching();

}

}

}

else if (currentState == SEARCHING) {

// Search mode processing

if (checkDisturbances()) {

stopMotors();

disturbanceDetected = true;

flashSearchLights();

}

if (millis() - searchPhaseStart >= SEARCH_DURATION) {

transitionToMoving();

}

}

}

void handleStandby() {

setLedState(STANDBY);

stopMotors();

// Wait for IR command to transition to moving

}

void handleMoving() {

static unsigned long lastObstacleTime = 0;

const unsigned long obstacleCooldown = 1000; // 1 second cooldown

setLedState(MOVING);

// Initialization on state entry

if (!initialCalibrationDone) {

calibrateGyro();

initialCalibrationDone = true;

resetEncoders();

accumulatedDistance = 0;

Serial.println("Starting movement to 5ft");

}

// Check for obstacles with cooldown

if (millis() - lastObstacleTime > obstacleCooldown && checkFrontObstacle()) {

handleObstacle();

lastObstacleTime = millis();

return;

}

// Normal movement

moveForward();

updateDistance();

// Check completion

if (accumulatedDistance >= TARGET_DISTANCE) {

Serial.println("Reached 5ft target");

transitionToSearching();

initialCalibrationDone = false;

}

}

void handleSearching() {

static bool stabilizationDone = false;

// State entry initialization

if (!stabilizationDone) {

setLedState(SEARCHING);

stopMotors();

searchPhaseStart = millis();

stabilizationDone = true;

disturbanceDetected = false;

digitalWrite(BLUE, HIGH);

digitalWrite(buzzerPin, LOW); // Ensure buzzer starts quiet

delay(SEARCH_STABILIZE_TIME); // Sensor stabilization

}

// Check sensors

if (checkDisturbances()) {

flashSearchLights(); // This now handles both LEDs and buzzer

} else {

// Ensure buzzer is off when no disturbance

digitalWrite(buzzerPin, LOW);

}

// Time-based state exit

if (millis() - searchPhaseStart >= SEARCH_DURATION) {

stabilizationDone = false;

transitionToMoving();

}

}

/***************************** New Helper Functions **********************************/

bool checkFrontObstacle() {

VL53L0X_RangingMeasurementData_t measure;

loxMidLeft.rangingTest(&measure, false);

return (measure.RangeMilliMeter <= 610 && measure.RangeStatus != 4); // 2ft = ~610mm

}

void handleObstacle() {

stopMotors();

delay(500); // Pause before turning

// Random turn (100-280 degrees) with direction based on sensor reading

int turnAngle = random(100, 280);

bool turnRight = random(0, 2); // Random direction

Serial.print("Obstacle! Turning ");

Serial.print(turnAngle);

Serial.println(turnRight ? "° right" : "° left");

if (turnRight) {

performGyroTurn(turnAngle);

} else {

performGyroTurn(-turnAngle); // Negative for left turn

}

// Resume movement

moveForward();

}

void performGyroTurn(float degrees) {

float targetYaw = yaw + degrees;

float startYaw = yaw;

vL = 210-((omega * wheelbase) / 2)*0.152;

vR = 255-((omega * wheelbase) / 2)*0.152;

// Determine turn direction

bool turnRight = degrees > 0;

digitalWrite(leftdirpin, HIGH);

digitalWrite(rightdirpin, HIGH);

// Apply turning power

analogWrite(leftpwmpin, vL);

analogWrite(rightpwmpin, vR);

// Wait until target reached

while (abs(yaw - targetYaw) > 2.0) {

updateGyro();

Serial.println(yaw);

delay(10);

}

stopMotors();

Serial.print("Turn completed. Final yaw: ");

Serial.println(yaw);

}

void updateDistance() {

// Convert encoder ticks to distance (mm)

float leftDistance = (leftencoderpulse / tpr) * ipr * 25.4;

float rightDistance = (rightencoderpulse / tpr) * ipr * 25.4;

accumulatedDistance = (leftDistance + rightDistance) / 2.0; // Average of both wheels

Serial.print("Distance: ");

Serial.print(accumulatedDistance / 304.8, 2); // Display in feet with 2 decimals

Serial.println(" ft");

}

void transitionToSearching() {

digitalWrite(buzzerPin, LOW); // Ensure buzzer off when entering search

currentState = SEARCHING;

searchPhaseStart = millis();

setLedState(SEARCHING); // Explicitly set LED state

Serial.println("Transitioning to Search Mode");

}

void transitionToMoving() {

digitalWrite(buzzerPin, LOW); // Ensure buzzer off when leaving search

currentState = MOVING;

accumulatedDistance = 0;

resetEncoders();

setLedState(MOVING); // Explicitly set LED state

Serial.println("Resuming Movement");

}

void flashSearchLights() {

static unsigned long lastFlashTime = 0;

if (millis() - lastFlashTime >= beepInterval) {

lastFlashTime = millis();

// Toggle both LEDs and buzzer together

flashState = !flashState;

if (flashState) {

// Purple (Red + Blue) + Buzzer ON

digitalWrite(RED, HIGH);

digitalWrite(GREEN, LOW);

digitalWrite(BLUE, HIGH);

digitalWrite(buzzerPin, HIGH);

} else {

// Cyan (Green + Blue) + Buzzer OFF

digitalWrite(RED, LOW);

digitalWrite(GREEN, HIGH);

digitalWrite(BLUE, HIGH);

digitalWrite(buzzerPin, LOW);

}

}

}

/***************************** Modified IR Functions **********************************/

void translateIR() {

if (irrecv.decode()) {

static unsigned long lastIRTime = 0;

unsigned long currentTime = millis();

// Debounce - ignore repeats within 200ms

if (currentTime - lastIRTime > 200) {

lastIRTime = currentTime;

switch(irrecv.decodedIRData.decodedRawData) {

case 0xBA45FF00: // POWER

if (currentState == OFF) {

currentState = STANDBY; // OFF → STANDBY

} else if (currentState == STANDBY) {

currentState = MOVING; // STANDBY → MOVING

} else {

currentState = OFF; // MOVING/SEARCHING → OFF

}

setLedState(currentState);

break;

case 0xB847FF00: // RESET

currentState = STANDBY; // Force reset to STANDBY

accumulatedDistance = 0;

resetEncoders();

setLedState(currentState);

break;

}

}

irrecv.resume();

}

}

/***************************** Motor Control Enhancements **********************************/

void moveForward() {

digitalWrite(leftdirpin, HIGH);

digitalWrite(rightdirpin, LOW);

analogWrite(leftpwmpin, 110);

analogWrite(rightpwmpin, 200);

}

void resetEncoders() {

leftencoderpulse = 0;

rightencoderpulse = 0;

}

void ALeadingLeft() {

if(digitalRead(leftencoderBpin) == LOW) leftencoderpulse--;

else leftencoderpulse++;

}

void BLeadingLeft() {

if(digitalRead(leftencoderApin) == LOW) leftencoderpulse++;

else leftencoderpulse--;

}

void ALeadingRight() {

if(digitalRead(rightencoderBpin) == LOW) rightencoderpulse++;

else rightencoderpulse--;

}

void BLeadingRight() {

if(digitalRead(rightencoderApin) == LOW) rightencoderpulse--;

else rightencoderpulse++;

}

void stopMotors() {

digitalWrite(leftdirpin, HIGH);

digitalWrite(rightdirpin, LOW);

analogWrite(leftpwmpin, 255);

analogWrite(rightpwmpin, 0);

}

void handleOff() {

digitalWrite(RED, HIGH);

digitalWrite(GREEN, LOW);

digitalWrite(BLUE, LOW);

stopMotors();

}

/***************************** Sensor Functions **********************************/

bool checkDisturbances() {

// Check PIR sensors

bool motionDetected = digitalRead(pirPin1) || digitalRead(pirPin2) || digitalRead(pirPin3) || digitalRead(pirPin4);

// Check sound with threshold

bool soundDetected = analogRead(sensorAnalogPin) > loudNoiseThreshold;

if ((motionDetected || soundDetected) &&

(millis() - lastDisturbanceTime > debounceTime)) {

lastDisturbanceTime = millis();

return true;

}

return false;

}

void calibrateSensor() {

long sum = 0;

for(int i = 0; i < 50; i++) {

sum += analogRead(sensorAnalogPin);

delay(20);

}

loudNoiseThreshold = (sum / 50) + 400;

Serial.print("Sound threshold: ");

Serial.println(loudNoiseThreshold);

}

void resetSystem() {

currentState = OFF;

accumulatedDistance = 0;

yaw = 0;

leftencoderpulse = 0;

rightencoderpulse = 0;

stopMotors();

setLedState(OFF);

}

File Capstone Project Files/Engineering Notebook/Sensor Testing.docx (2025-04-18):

## Nav sensors

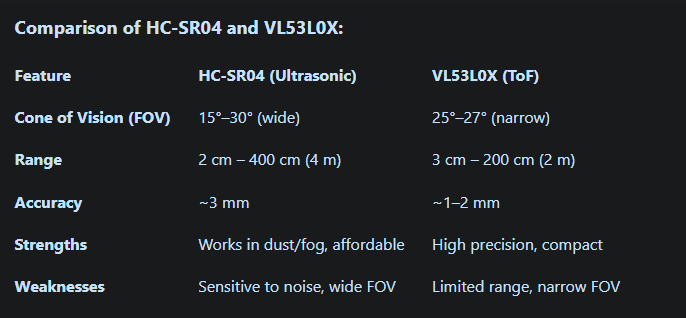
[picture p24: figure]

## LM393 Sound Sensor (all tested, all work)

(soundsensor.ino)

- adjust the pot to adjust the sensitivity

https://github.com/BasOnTech/Arduino-Beginners-EN/blob/master/E30-sound-sensor/E30-sound-sensor-part-2/E30-sound-sensor-part-2.ino

## HC SR501 PIR (all tested, all work)

(sensorcode.ino)

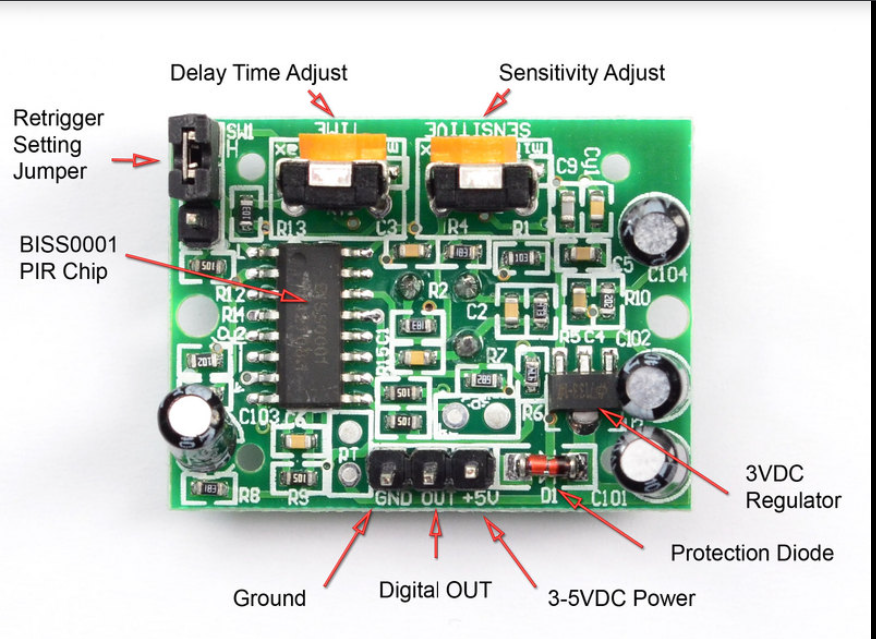
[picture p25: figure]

- very finicky
  - adjust the time delay and sensitivity knobs, motion trigger jumper (place on high)

https://lastminuteengineers.com/pir-sensor-arduino-tutorial/

^^^^^^^ completely shows you how to adjust and use adjust switches ^^^^^^^

## ULTRASONIC

- all good

https://projecthub.arduino.cc/Isaac100/getting-started-with-the-hc-sr04-ultrasonic-sensor-7cabe1

## TIME OF FLIGHT

- install Adafruit_VL53L0X on the IDE
- All 5 ToF sensors work, and different distances were tested to verify accuracy
  - Note that pins GPI01 and XSHUT were not used in testing
- https://www.youtube.com/watch?v=EvaYQMMEtvg (used but different code used)

#include <Wire.h>

#include "Adafruit_VL53L0X.h"

Adafruit_VL53L0X lox = Adafruit_VL53L0X();

void setup() {

Serial.begin(115200);

Wire.begin(); // Initialize I2C

Serial.println("Adafruit VL53L0X test");

if (!lox.begin()) {

Serial.println(F("Failed to boot VL53L0X"));

while(1);

}

Serial.println(F("VL53L0X API Simple Ranging example\n\n"));

}

void loop() {

VL53L0X_RangingMeasurementData_t measure;

lox.rangingTest(&measure, false);

if (measure.RangeStatus != 4) {

Serial.print("Distance (mm): ");

Serial.println(measure.RangeMilliMeter);

} else {

Serial.println("Out of range");

}

delay(100);

}

- Four sensor ToF

#include <Wire.h>

#include "Adafruit_VL53L0X.h"

// Define sensor objects with position labels

Adafruit_VL53L0X loxFarRight = Adafruit_VL53L0X(); // Pin 4

Adafruit_VL53L0X loxMidRight = Adafruit_VL53L0X(); // Pin 5

Adafruit_VL53L0X loxMidLeft = Adafruit_VL53L0X(); // Pin 6

Adafruit_VL53L0X loxFarLeft = Adafruit_VL53L0X(); // Pin 7

// Define XSHUT pins for each position

#define XSHUT_FAR_RIGHT 4

#define XSHUT_MID_RIGHT 5

#define XSHUT_MID_LEFT 6

#define XSHUT_FAR_LEFT 7

void setup() {

Serial.begin(9600);

Wire.begin(); // Initialize I2C

// Set XSHUT pins as outputs

pinMode(XSHUT_FAR_RIGHT, OUTPUT);

pinMode(XSHUT_MID_RIGHT, OUTPUT);

pinMode(XSHUT_MID_LEFT, OUTPUT);

pinMode(XSHUT_FAR_LEFT, OUTPUT);

// Initialize sensors in order (prevents address conflicts)

initializeSensor(loxFarRight, XSHUT_FAR_RIGHT, 0x30, "Far Right");

initializeSensor(loxMidRight, XSHUT_MID_RIGHT, 0x31, "Middle Right");

initializeSensor(loxMidLeft, XSHUT_MID_LEFT, 0x32, "Middle Left");

initializeSensor(loxFarLeft, XSHUT_FAR_LEFT, 0x33, "Far Left");

Serial.println(F("All sensors initialized!"));

}

void loop() {

// Read and print distances with position labels

readSensor(loxFarRight, "Far Right");

readSensor(loxMidRight, "Middle Right");

readSensor(loxMidLeft, "Middle Left");

readSensor(loxFarLeft, "Far Left");

delay(1000); // Adjust for robot responsiveness

}

// Function to initialize a sensor with a unique address and label

void initializeSensor(Adafruit_VL53L0X &sensor, int xshutPin, uint8_t newAddress, const char* position) {

// Reset the sensor (pull XSHUT low, then high)

digitalWrite(xshutPin, LOW);

delay(10);

digitalWrite(xshutPin, HIGH);

delay(10);

// Initialize with the new address

if (!sensor.begin(newAddress)) {

Serial.print(position);

Serial.println(F(" sensor failed to boot!"));

while (1); // Halt if a sensor fails

}

Serial.print(position);

Serial.print(F(" sensor initialized at address 0x"));

Serial.println(newAddress, HEX);

}

// Function to read and print sensor data

void readSensor(Adafruit_VL53L0X &sensor, const char* position) {

VL53L0X_RangingMeasurementData_t measure;

sensor.rangingTest(&measure, false); // Get distance

if (measure.RangeStatus != 4) {

Serial.print(position);

Serial.print(": ");

Serial.print(measure.RangeMilliMeter);

Serial.println(" mm");

} else {

Serial.print(position);

Serial.println(": Out of range");

}

}

## IR Sensor with Remote control from kit

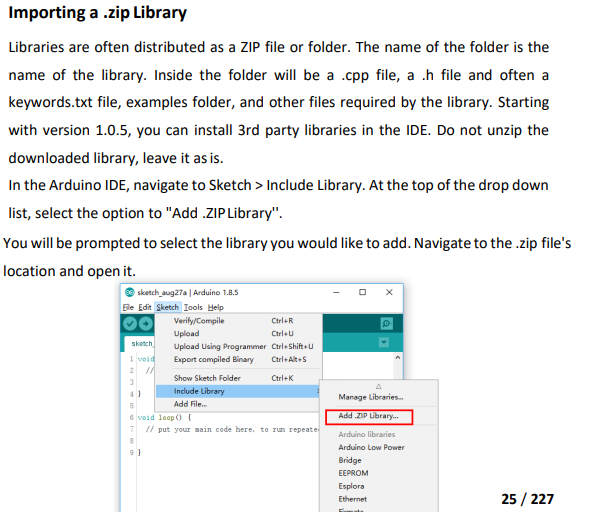
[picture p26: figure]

The library is given with Elegoo mega kit document, and is on Sheldon’s computer for testing the remote control.

- Works and can tell which input is pressed on the remote

## HC-SR501 PIR Sensor

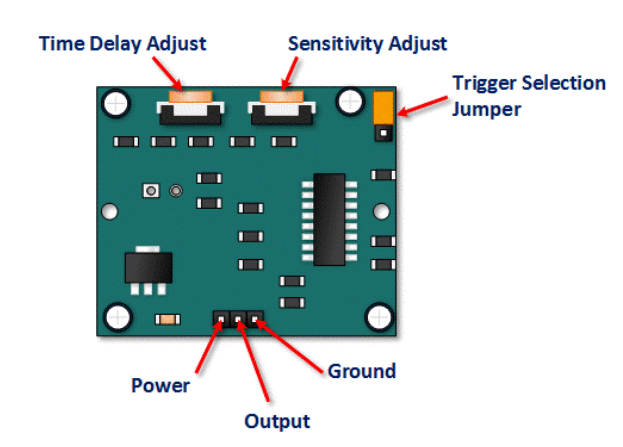
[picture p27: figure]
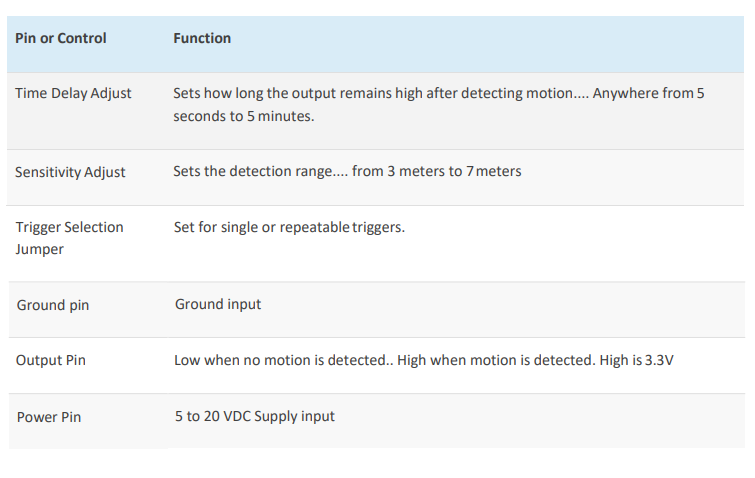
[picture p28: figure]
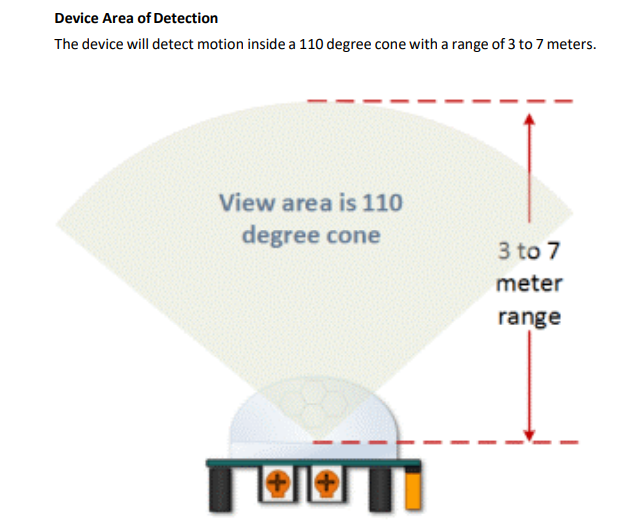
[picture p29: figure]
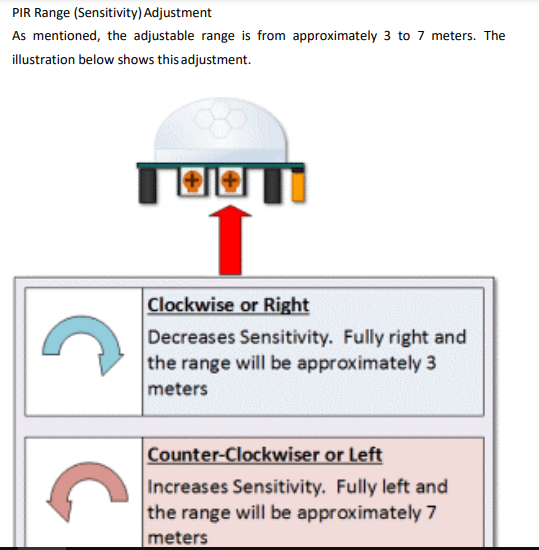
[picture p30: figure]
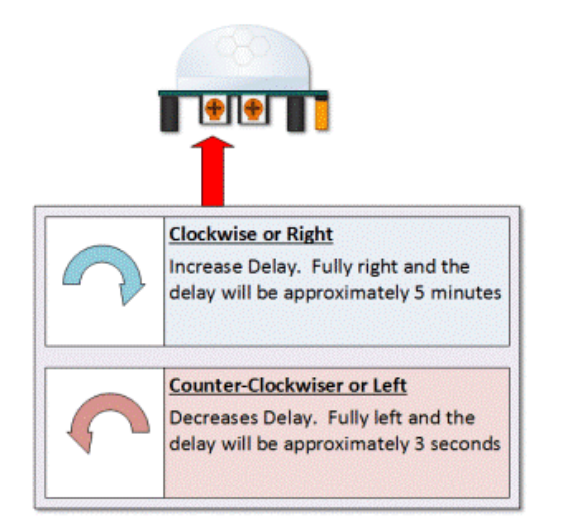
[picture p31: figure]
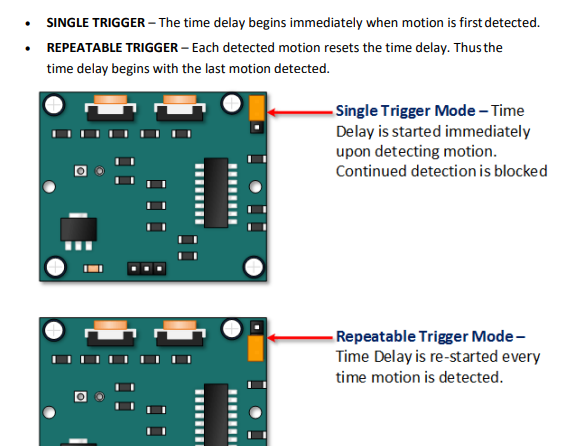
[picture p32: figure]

## GYRO MPU9250 /GY-521

- install mpu9250 gyro library on arduino ide
- vcc to 5v, gnd to gnd, scl to _____, sda to ____

Revised
#include <Wire.h>

// MPU-6050 I2C address

const int MPU_addr = 0x68;

// Gyroscope and accelerometer vars

int16_t AcX, AcY, AcZ, GyX, GyY, GyZ;

float gyroX, gyroY, gyroZ; // Angular velocity in °/s

float accX, accY, accZ; // Accelerometer data in g

// Orientation variables

float roll, pitch, yaw; // Roll, pitch, and yaw angles

//Note: Dependent on how the sensor is place affects these (roll and pitch are switched currently)

float rollAcc, pitchAcc; // Roll and pitch from accelerometer

// Complementary filter variables

float alpha = 0.98; // Weight for gyroscope data (tune this value if needed)

// Timing variables

float dt; // Time interval

unsigned long prevTime; // Previous time stamp

// Gyroscope sensitivity scale factor (for ±250°/s range)

const float GYRO_SCALE = 131.0;

// Accelerometer sensitivity scale factor (for ±2g range)

const float ACCEL_SCALE = 16384.0;

void setup() {

Wire.begin();

Serial.begin(9600);

// Initialize MPU-6050

Wire.beginTransmission(MPU_addr);

Wire.write(0x6B); // PWR_MGMT_1 register

Wire.write(0); // Wake up the MPU-6050

Wire.endTransmission(true);

// Initialize variables

roll = 0;

pitch = 0;

yaw = 0;

prevTime = micros();

}

void loop() {

// Read accelerometer and gyroscope data

Wire.beginTransmission(MPU_addr);

Wire.write(0x3B); // Start with register 0x3B (ACCEL_XOUT_H)

Wire.endTransmission(false);

Wire.requestFrom(MPU_addr, 14, true); // Request 14 registers

// Read accelerometer data

AcX = Wire.read() << 8 | Wire.read();

AcY = Wire.read() << 8 | Wire.read();

AcZ = Wire.read() << 8 | Wire.read();

// Read temperature data (not used in this example)

Wire.read() << 8 | Wire.read();

// Read gyroscope data

GyX = Wire.read() << 8 | Wire.read();

GyY = Wire.read() << 8 | Wire.read();

GyZ = Wire.read() << 8 | Wire.read();

// Convert raw accelerometer data to g

accX = AcX / ACCEL_SCALE;

accY = AcY / ACCEL_SCALE;

accZ = AcZ / ACCEL_SCALE;

// Convert raw gyroscope data to °/s

gyroX = GyX / GYRO_SCALE;

gyroY = GyY / GYRO_SCALE;

gyroZ = GyZ / GYRO_SCALE;

// Calculate time interval

unsigned long currentTime = micros();

dt = (currentTime - prevTime) / 1000000.0; // Convert to seconds

prevTime = currentTime;

// Calculate roll and pitch from accelerometer

rollAcc = atan2(accY, accZ) * 180 / PI;

pitchAcc = atan2(-accX, sqrt(accY * accY + accZ * accZ)) * 180 / PI;

// Apply complementary filter to combine gyroscope and accelerometer data

roll = alpha * (roll + gyroX * dt) + (1 - alpha) * rollAcc;

pitch = alpha * (pitch + gyroY * dt) + (1 - alpha) * pitchAcc;

yaw += gyroZ * dt; // Yaw is only from gyroscope (no accelerometer correction)

// Print orientation

Serial.print("Pitch: ");

Serial.print(roll);

Serial.print(" | Roll: ");

Serial.print(pitch);

Serial.print(" | Yaw: ");

Serial.println(yaw);

delay(10); // Small delay for stability

}

// MPU-6050 Short Example Sketch

//www.elegoo.com

//2016.12.9

#include<Wire.h>

const int MPU_addr = 0x68; // I2C address of the MPU-6050

int16_t GyX, GyY, GyZ;

void setup(){

Wire.begin();

Wire.beginTransmission(MPU_addr);

Wire.write(0x6B); // PWR_MGMT_1 register

Wire.write(0); // set to zero (wakes up the MPU-6050)

Wire.endTransmission(true);

Serial.begin(9600);

}

void loop(){

Wire.beginTransmission(MPU_addr);

Wire.write(0x3B); // starting with register 0x3B (ACCEL_XOUT_H)

Wire.endTransmission(false);

Wire.requestFrom(MPU_addr,14,true); // request a total of 14 registers

GyX = Wire.read()<<8|Wire.read(); // 0x43 (GYRO_XOUT_H) & 0x44 (GYRO_XOUT_L)

GyY = Wire.read()<<8|Wire.read(); // 0x45 (GYRO_YOUT_H) & 0x46 (GYRO_YOUT_L)

GyZ = Wire.read()<<8|Wire.read(); // 0x47 (GYRO_ZOUT_H) & 0x48 (GYRO_ZOUT_L)

Serial.print("X = "); Serial.println(GyX);

Serial.print("Y = "); Serial.println(GyY);

Serial.print("Z = "); Serial.println(GyZ);

Serial.println();

delay(500);

}

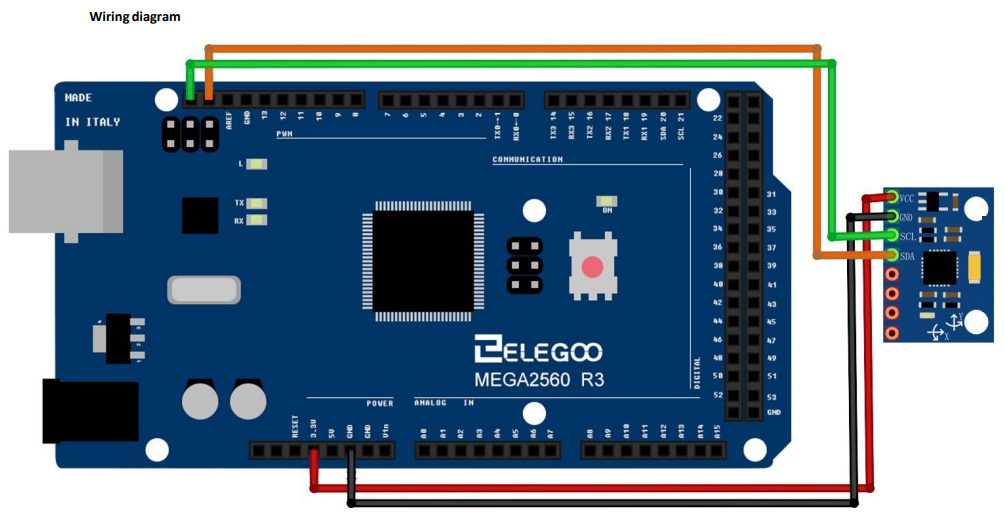
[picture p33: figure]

vgggggg

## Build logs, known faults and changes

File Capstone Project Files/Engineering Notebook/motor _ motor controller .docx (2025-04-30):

yellow motor controller (https://www.amazon.com/RioRand-Brushless-Electric-Controller-Hall-Less/dp/B087M2378D)

RED motor controller (https://www.amazon.com/RioRand-Brushless-Electric-Controller-Hall-Less/dp/B087M2378D)

robot shop link to the motors (https://www.robotshop.com/products/e-s-motor-28mm-brushless-dc-planetary-gear-motor-12v-68rpm)

says what the motor wires are (mostly) (https://cdn.robotshop.com/rbm/a00a7635-653b-4220-aac9-b0c23c5c5e2c/e/e8115577-62ef-460b-929e-61753e141324/3f7f3db6_28pg-2838bl-motor.pdf)

From amazon page

- right, so this is what the motor controllers would want if we had a hall MOTOR. what we have is a bldc single phase motor with hall ENCODER capabilities. if/when we decide to use this, our single motor wire would go somewhere in the ha hb hc terminals, where the giant white plug is (we are only using vcc and gnd as of right now)

Possible Helpful Links for Arduino stuffs

https://mad-ee.com/controlling-a-hoverboard-motor-with-a-simple-arduino/ (pin assignment and analog write, which helps to set a pwm value)

- DIR on the mc might need to go to a pin on the mega instead of the motor pin going to the mc

https://docs.cirkitdesigner.com/component/4cf35777-c70f-44c9-9828-838f50915cea/zs-x11h-v2-350w-motor-controller

Test code for both motors

// Pin definitions for RIGHT motor

const int rightPwmPin = 9; // PWM pin for speed control (Blue)

const int rightDirPin = 8; // Digital pin for direction control (White)

const int rightFgPin = 2; // FG signal input for speed measurement (Yellow)

// Pin definitions for LEFT motor

const int leftPwmPin = 11; // PWM pin for speed control (Blue)

const int leftDirPin = 10; // Digital pin for direction control (White)

const int leftFgPin = 3; // FG signal input for speed measurement (Yellow)

// Variables for speed measurement

volatile int rightPulseCount = 0; // Counter for RIGHT motor FG pulses

volatile int leftPulseCount = 0; // Counter for LEFT motor FG pulses

unsigned long lastTime = 0; // Time of last RPM calculation

void setup() {

// Set pin modes for RIGHT motor

pinMode(rightPwmPin, OUTPUT);

pinMode(rightDirPin, OUTPUT);

pinMode(rightFgPin, INPUT);

// Set pin modes for LEFT motor

pinMode(leftPwmPin, OUTPUT);

pinMode(leftDirPin, OUTPUT);

pinMode(leftFgPin, INPUT);

// Attach interrupts to FG pins for pulse counting

attachInterrupt(digitalPinToInterrupt(rightFgPin), rightPulse, RISING);

attachInterrupt(digitalPinToInterrupt(leftFgPin), leftPulse, RISING);

// Initialize serial communication for debugging

Serial.begin(9600);

// Initialize motor directions (HIGH = CW, LOW = CCW)

digitalWrite(rightDirPin, HIGH); // Set initial direction to clockwise

digitalWrite(leftDirPin, HIGH); // Set initial direction to clockwise

}

void loop() {

// Example: Move robot forward for 5 seconds

moveForward(128); // 50% speed

delay(5000);

// Example: Move robot backward for 5 seconds

moveBackward(128); // 50% speed

delay(5000);

// Example: Turn robot right for 2 seconds

turnRight(128); // 50% speed

delay(2000);

// Example: Turn robot left for 2 seconds

turnLeft(128); // 50% speed

delay(2000);

// Example: Stop the robot

stopMotors();

delay(2000);

}

// Function to move robot forward

void moveForward(int speed) {

// Set both motors to move forward

digitalWrite(rightDirPin, HIGH); // RIGHT motor forward

digitalWrite(leftDirPin, HIGH); // LEFT motor forward

analogWrite(rightPwmPin, speed); // Set RIGHT motor speed

analogWrite(leftPwmPin, speed); // Set LEFT motor speed

}

// Function to move robot backward

void moveBackward(int speed) {

// Set both motors to move backward

digitalWrite(rightDirPin, LOW); // RIGHT motor backward

digitalWrite(leftDirPin, LOW); // LEFT motor backward

analogWrite(rightPwmPin, speed); // Set RIGHT motor speed

analogWrite(leftPwmPin, speed); // Set LEFT motor speed

}

// Function to turn robot right

void turnRight(int speed) {

// RIGHT motor backward, LEFT motor forward

digitalWrite(rightDirPin, LOW); // RIGHT motor backward

digitalWrite(leftDirPin, HIGH); // LEFT motor forward

analogWrite(rightPwmPin, speed); // Set RIGHT motor speed

analogWrite(leftPwmPin, speed); // Set LEFT motor speed

}

// Function to turn robot left

void turnLeft(int speed) {

// RIGHT motor forward, LEFT motor backward

digitalWrite(rightDirPin, HIGH); // RIGHT motor forward

digitalWrite(leftDirPin, LOW); // LEFT motor backward

analogWrite(rightPwmPin, speed); // Set RIGHT motor speed

analogWrite(leftPwmPin, speed); // Set LEFT motor speed

}

// Function to stop both motors

void stopMotors() {

analogWrite(rightPwmPin, 0); // Stop RIGHT motor

analogWrite(leftPwmPin, 0); // Stop LEFT motor

}

// Interrupt service routine to count RIGHT motor FG pulses

void rightPulse() {

rightPulseCount++;

}

// Interrupt service routine to count LEFT motor FG pulses

void leftPulse() {

leftPulseCount++;

}

// Function to calculate RPM for RIGHT motor

int calculateRightRPM() {

unsigned long currentTime = millis();

unsigned long elapsedTime = currentTime - lastTime;

// Calculate RPM: (pulses / 9) * (60000 / elapsedTime)

int rpm = (rightPulseCount / 9) * (60000 / elapsedTime);

// Reset pulse count and update lastTime

rightPulseCount = 0;

lastTime = currentTime;

return rpm;

}

// Function to calculate RPM for LEFT motor

int calculateLeftRPM() {

unsigned long currentTime = millis();

unsigned long elapsedTime = currentTime - lastTime;

// Calculate RPM: (pulses / 9) * (60000 / elapsedTime)

int rpm = (leftPulseCount / 9) * (60000 / elapsedTime);

// Reset pulse count and update lastTime

leftPulseCount = 0;

lastTime = currentTime;

return rpm;

}

Code That We Know Makes It Move

// Pin definitions

const int pwmPin = 9; // PWM pin for speed control (Blue)

const int dirPin = 8; // Digital pin for direction control (White)

const int fgPin = 2; // FG signal input for speed measurement (Yellow)

// Variables for speed measurement

volatile int pulseCount = 0; // Counter for FG pulses

unsigned long lastTime = 0; // Time of last RPM calculation

void setup() {

// Set pin modes

pinMode(pwmPin, OUTPUT);

pinMode(dirPin, OUTPUT);

pinMode(fgPin, INPUT);

// Attach interrupt to FG pin for pulse counting

attachInterrupt(digitalPinToInterrupt(fgPin), countPulses, RISING);

// Initialize serial communication for debugging

Serial.begin(9600);

// Initialize motor direction (HIGH = CW, LOW = CCW)

digitalWrite(dirPin, HIGH); // Set initial direction to clockwise

}

void loop() {

// Example: Rotate motor clockwise at 50% speed

digitalWrite(dirPin, HIGH); // Set direction to clockwise

analogWrite(pwmPin, 128); // Set speed to 50% (PWM value 128/255)

delay(5000); // Run for 5 seconds

// Measure and print RPM

int rpm = calculateRPM();

Serial.println("Clockwise RPM: " + String(rpm));

// Example: Rotate motor counterclockwise at 75% speed

digitalWrite(dirPin, LOW); // Set direction to counterclockwise

analogWrite(pwmPin, 192); // Set speed to 75% (PWM value 192/255)

delay(5000); // Run for 5 seconds

// Measure and print RPM

rpm = calculateRPM();

Serial.println("Counterclockwise RPM: " + String(rpm));

// Example: Stop the motor

analogWrite(pwmPin, 0); // Set speed to 0% (motor stops)

delay(2000); // Wait for 2 seconds

}

// Interrupt service routine to count FG pulses

void countPulses() {

pulseCount++;

}

// Function to calculate RPM

int calculateRPM() {

unsigned long currentTime = millis();

unsigned long elapsedTime = currentTime - lastTime;

// Calculate RPM: (pulses / 9) * (60000 / elapsedTime)

int rpm = (pulseCount / 9) * (60000 / elapsedTime);

// Reset pulse count and update lastTime

pulseCount = 0;

lastTime = currentTime;

return rpm;

}

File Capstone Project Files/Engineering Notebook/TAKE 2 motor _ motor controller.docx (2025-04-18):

MOTOR WIRES

- red motor (+ and - switching can control CW/CCW)
- black encoder -(GND, “can not be connected wrong” I assume means that reversing the vcc and gnd means the motor moves backward)
- YELLOW encoder A phase (11 signals)
- GREEN encoder B phase (11 signals)
- blue encoder + (+ and - can not be connected wrong)
- white motor -(+ and - switching can control CW/CCW)

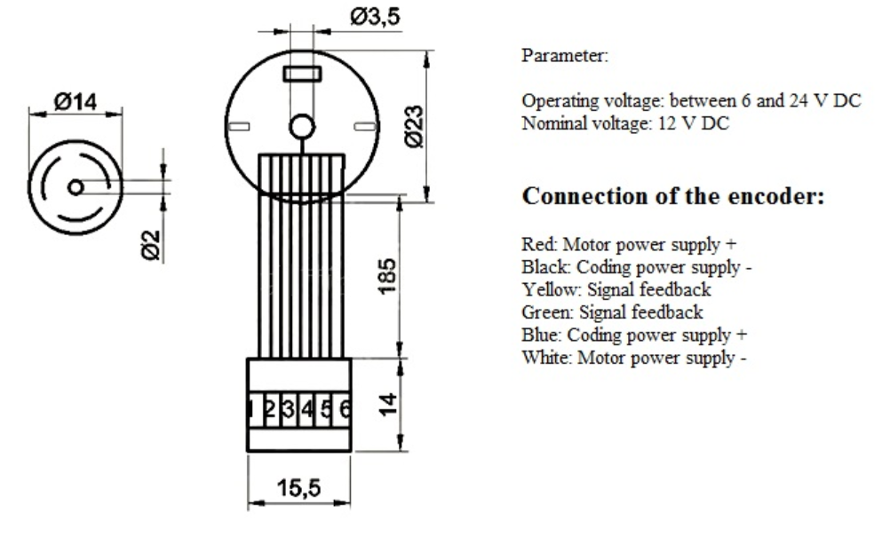
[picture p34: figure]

https://www.openimpulse.com/blog/wp-content/uploads/wpsc/downloadables/JGA25-371-technical-drawing-21.jpg

Interrupt pins on Arduino Mega: 2&3, 18&19, 20&21

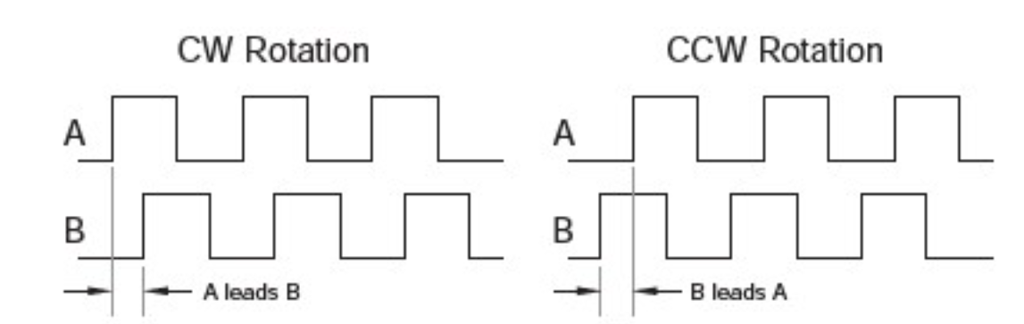
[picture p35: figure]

- ONE ROTATION OF OUR BIG ASS WHEEL IS 950 ENCODER TICKS!!!!
- LOW is 0-255
- HIGH is 255-0

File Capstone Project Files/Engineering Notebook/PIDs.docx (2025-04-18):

https://www.youtube.com/watch?v=HRaZLCBFVDE
